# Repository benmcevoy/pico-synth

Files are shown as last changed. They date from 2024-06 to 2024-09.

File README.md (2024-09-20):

# Raspberry Pi Pico "pico-synth"

Audio synthesizer running on a Raspberyy Pi Pico device.

Currently monophonic with TWO voices.

You WILL need to make a little circuit to drop the PWM voltage from 3.3 volts to about 1.1 volts and filter low/high noise out.  Or just risk it and plug in a speaker :)

Here is an example circuit: https://learn.adafruit.com/adding-basic-audio-ouput-to-raspberry-pi-zero/pi-zero-pwm-audio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

I use `qjackctl` on linux to connect a midi keyboard via my PC.  I have not tested it directly with a MIDI controller directly attached (no PC involved), I assume it will work :)

You can find a `synth.uf2` file in the build folder which can be copied onto the Pico (hold bootsel while powering on connecting to a PC).

This is about the third C project I have written in the last thirty years, so you know... all bugs are my own.

## Pico-SDK

For PIO USB needs to be on develop, at milestone 2.1 release should be back on master.

## TinyUSB

pico-sdk ships an older version of tinyusb, so i have pulled latest of that module in order to get the newer usb host code.

Must be >= v0.17

```
# update sdk
cd pico-sdk
git submodule update --init --recursive

# update tiny-usb
cd pico-sdk/lib/tinyusb
git pull origin master
```

Run to get the dependances for pio usb.

```
python3 tools/get_deps.py rp2040
```

midi host code from:  https://github.com/rppicomidi/usb_midi_host

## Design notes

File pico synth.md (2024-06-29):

# pico-synth

DONE - solder on some headers

DONE - add a reset button pin 30 short to ground

## DONE - toolchain

installed mostly as per 

`https://raw.githubusercontent.com/raspberrypi/pico-setup/master/pico_setup.sh`

skipped OpenOCD and some pi related things

blink - it sure did

hello_world

`sudo dmesg`

shows the usb device

then we can monitor it

`sudo plink -serial /dev/ttyACM0 -sercfg 115200`

## CMAKE Build

if you just run cmake it makes an awful mess

i don't really know what i'm doing...

grabbed the example base cmake.txt and sdk import files as the basis

set the project to synth

in the synth project just include main.c to build, plus a bit of pico config

e.g.
```sh
pico_enable_stdio_usb(synth 1)
pico_enable_stdio_uart(synth 0)
```

prepare the build folder, from /src

```
mkdir build
cd build
cmake ..
```

this dumps a load of stuff in build

then cd into e.g. build/synth and

`make -j4`

or just `make`

cmake makes make.  duh...

## logging via uart

currently logging via usb.  i read that this is intensive compared to UART.

just turn on UART and turn off USB for stdio

```
pico_enable_stdio_usb(${projectName} 0)
pico_enable_stdio_uart(${projectName} 1)
```

for now, don't care.  it's more convient to use usb.

```sh
sudo plink -serial /dev/ttyACM0 -sercfg 115200
```

## wavetable on an irq

i have a header file from circle that has a sample in  it... let's nick it.

i assume that once started i have to go into some loop to stay alive...  what is the basic pattern here?

"The return code of main() is ignored by the SDK runtime, and the default behaviour is to hang the processor on exit."

so we can just loop through the sound.h array then exit.  no wukkas.

```
// set up pwm
// setup an irq to provide a nice clock
// the sample is 44.1kHz and 8 bit
```

pointer into an array is going to be *char++ something like that... to step 8 bits/byte per step

some code from the pico example:

```c
// Tell GPIO 0 and 1 they are allocated to the PWM
    gpio_set_function(0, GPIO_FUNC_PWM);
    gpio_set_function(1, GPIO_FUNC_PWM);

    // Find out which PWM slice is connected to GPIO 0 (it's slice 0)
    uint slice_num = pwm_gpio_to_slice_num(0);

    // Set period of 4 cycles (0 to 3 inclusive)
    pwm_set_wrap(slice_num, 3);
    // Set channel A output high for one cycle before dropping
    pwm_set_chan_level(slice_num, PWM_CHAN_A, 1);
    // Set initial B output high for three cycles before dropping
    pwm_set_chan_level(slice_num, PWM_CHAN_B, 3);
    // Set the PWM running
    pwm_set_enabled(slice_num, true);
```

**what is a slice?**

in the sdk docs and the datasheet it is not defined.  but i think that PWM has a master clock then subdivides that up into 8 or 16 "slices"? so each slice has some clock to tell it when to go high, go low.

https://www.codrey.com/raspberry-pi/raspberry-pi-pico-pwm-primer/

so, pin0 has associated slice number 0A  that's not HEX mind, that's 0 channel A

and pin1 is channel b e.g. 0B

so we do get 16 "channels" on 8 "slices"

**what is a wrap?**

guessing this is when the pwm counter wraps?

it's also not defined, thanks for that.

looks like

```
channelA: -___-___-___
channelb: ---_---_---_
```

so this example is not really what we want.

https://www.raspberrypi.com/documentation/pico-sdk/hardware.html#hardware_pwm

this is better but still assumes an awful lot...

https://www.raspberrypi.com/documentation/pico-sdk/hardware.html#detailed-description109

ok rtfm...

another example ticks some boxes...

```c
    // Tell the LED pin that the PWM is in charge of its value.
    gpio_set_function(PICO_DEFAULT_LED_PIN, GPIO_FUNC_PWM);
    // Figure out which slice we just connected to the LED pin
    uint slice_num = pwm_gpio_to_slice_num(PICO_DEFAULT_LED_PIN);

    // Mask our slice's IRQ output into the PWM block's single interrupt line,
    // and register our interrupt handler
    pwm_clear_irq(slice_num);
    pwm_set_irq_enabled(slice_num, true);
    irq_set_exclusive_handler(PWM_IRQ_WRAP, on_pwm_wrap);
    irq_set_enabled(PWM_IRQ_WRAP, true);

    // Get some sensible defaults for the slice configuration. By default, the
    // counter is allowed to wrap over its maximum range (0 to 2**16-1)
    pwm_config config = pwm_get_default_config();
    // Set divider, reduces counter clock to sysclock/this value
    pwm_config_set_clkdiv(&config, 4.f);
    // Load the configuration into our PWM slice, and set it running.
    pwm_init(slice_num, &config, true);

    // Everything after this point happens in the PWM interrupt handler, so we
    // can twiddle our thumbs
    while (1)
        tight_loop_contents();
```

What is sysclock frequency?  125 MHz?  this ain't no c64...

to get 44.1kHz i need a divider of?  2834.467120181

looking at some other example the wrap also affects this.

it's not clear yet.

but at 125Mhz

we can set a wrap of 254

and a divider of 12

and get 41010.498687664 Hz

close enough.

this example tweaks the sys clock to to get a nicer audio clock

https://github.com/rgrosset/pico-pwm-audio/blob/main/pico-pwm-audio.c

oh this line: `irq_set_exclusive_handler(PWM_IRQ_WRAP, on_pwm_wrap);`

well...

https://www.raspberrypi.com/documentation/pico-sdk/hardware.html#interrupt-numbers

feck.

so, i assumed the pwm level would be 16 bit.

oh, is it tied to the wrap level?

anyway, send an 8bit value works.

my clock speed was correct too.

ah, better the rp2040 datasheet has more info

https://datasheets.raspberrypi.com/rp2040/rp2040-datasheet.pdf

- interrupt request and DMA request on counter wrap

well that's handy....

wrap is a terrible name, it's the trigger level.

if i want to send 16bit samples i set wrap to 65535

oh, which gives me 1900 HERTZ!  bit slow...

yes that seems to be the case.  but the clock speed is no good

i can run at 12 bit and get about 31kHz

sounds correct too.

ok.

so for the reality situation

8 bit sound

a wrap of 255 or so

and in fact our original values are pretty good for 44.1kHz

we can probably drop to 22kHz

wrap:255

div:22

lands us at about 22.3kHz

as our sample is 44.1 we have to increment the index TWICE to make it about right.,

that is my hypothesis, let us try.

it is so.

ok, better read the rp2040 datasheet then...

Before looking at DMA I want to look at buffers.

I am thinking I need two buffers.  one is being streamed to the PWM while the other is filled.

when the buffer is empty i swap over.

is that normal? double buffering?

a search says "yes" this is sane.  the decision is mainly one of latency.

for DMA double bufferering appears to be necessary.

In BELA they use block based processing, which is buffers.

```cpp
// setup() runs once at the beginning of your program
bool setup(BelaContext *context, void *userData)
{
    // etc
}

// render() is called repeatedly by Bela for each audio block
void render(BelaContext *context, void *userData)
{
    // etc
}

// cleanup() runs once at the end of the program
void cleanup(BelaContext *context, void *userData)
{
}
```

the context provides several things, audio buffers, analog buffers, digital buffers, bidirectional too.

we care only for an audioOut buffer and samplesElapsed

also, I do not need to care about "frames" that is how many channels per sample do i need to fill.

it's one channel, mono so it's all 1.  hence just  samplesElapsed (u64)

userData is just some user struct that get passed around, so more user context data. i do not care for now.

how did I write my synth?  I made a `MonoWaveStream` that just fills a buffer when asked. and it get's it's next byte from `_voice.Output(Time).Out.Value`

`Time` then is `samplesElapsed`

so, trying to port my code...

I want a `Device` that has two buffers and 

- a pointer that tracks the current buffer 
- a read index

on the IRQ we just read another value from the buffer.

the device should also handle setting up sample rate but not bit depth as we can't really go beyond 8 bit

my code return `short` 16 bit samples. ok, deal with that later.

the Pico SDK is C/C++ so I can use that if need be.

how do i fill the buffer while continuing to service the irq?

threads? trigger another IRQ when swapping buffers?

skimming throught he examples, DMA offers control block chain - which is basically an array of buffers, or raise an IRQ when data is needed

there are timers, which use the system timers e.g. alarms

i feel like raising another IRQ when we need data is fine and sane.

there is a `pico_audio_pwm` sample in the `pico-extras`.  not making too much sense of it but:

it does some fancy things, like over-sampling and noise dithering (huh!?)

but how does it get it's data?

it defines audio buffer producer and consumer pools.

i can't follow the code but it looks like a DMA irq fires and asks for a new buffer....

i imagine the nice thing about using DMA+PIO is that a lot of the work that is NOT directly related to generating the next sample is offloaded to hardware and is very cycle exact etc.

but today that is beyond me.

SO.

## buffers and dma

Double buffer and use an IRQ to request more data.
do not care about DMA at this time.

fill the buffer so we can continuosly play a sine wave or something

ok. 

`Amplitude = sin(2*pi*f*t)`

and 

`t = samplesElapsed/sampleRate`

and sample rate as given in the rp2040 datasheet

`fsys = 125 MHz`

`fpwm = fsys/period`

`period = (WRAP+1)*(phase_correct+1)*(DIV+15/16)`

so we use wrap =254 and div =22 to get fpwm=21370.946198643

and that makes a noise that sounds fairly crap, lots of clicks and drift. 

lets add phase correction (halve the divider)

```
    pwm_config_set_clkdiv(&config, 11.f);
    pwm_config_set_wrap(&config, 254);
    pwm_config_set_phase_correct(&config, true);

```

not much better

hmm, wonder if it rentrant? make the buffers bigger

oh. that is an issue,  still clicks but much less.

BIGGER! 8k buffer!

actually it's a phase problem.  regular click.  

actually it's a bunch of bugs.  using `_samplesElapsed` which is still being incremented by the core0 while core1 tries to use it.

marshalling data to core1?  i think the FIFO is used? i just copy the value.  solid.

ok, reduce the buffer! 1k, just fine.

yeah buffer can be tiny, 32 bytes lol.

1 byte even.  ok, there's no real latency so far.

sweet as.

### PWM IRQ

From the docs:

"The same [PWM] pulse which sets the interrupt flag in INTR is also available as a one-cycle data request to the RP2040 system DMA. For each cycle the DMA sees a DREQ asserted, it will make one data transfer to its programmed location, in as timely a manner as possible. In combination with the double-buffered behaviour of CC and TOP, this allows the DMA to efficiently stream data to a PWM slice at a rate of one transfer per counter period. Alternatively, a PWM slice could serve as a pacing timer for DMA transfers to some other memory-mapped hardware."

DMA IRQ or DREQ seems like the go then.  next step.

Also: "the PWM block can also be used as a source of regular interrupt requests for non-PWM-related purposes"

Like polling MIDI or ADC...

Choice.

### DMA/DREQ

I'm struggling to see what benefit I would get here...

It seems the DMA will stream data to the PWM on each WRAP IRQ, which is good

Then a DMA IRQ will fire when it's buffer is empty?

we can then more or less immediately swap buffers and let DMA continue while then going on to fill the next buffer

which looks like it could all happen on core0

in this way the PWM IRQ work becomes completely offloaded to hardware

and the actual work of producing samples only needs to be checked for at the right time, when the buffer is empty

ok.  so maybe i can see the benefit.

This example is helpful, as it is basically what I want to do, ping-pong between two buffers.

https://github.com/raspberrypi/pico-examples/issues/112#issuecomment-1405075256

also

https://github.com/GregAC/pico-stuff/blob/main/pwm_dma/pwm_dma_interrupt_sequence.c

OK, let's give that a crack.

managed to bodge that together.  It is working but sounds quite bad - buzzy.

might look on the old oscilloscope.  A PICO SCOPE no less!

the old way, just the irq on the pwm produces some PWMish looking stuff
the new way produces a spike at 440Hz, click click click

i assume my config is not good.

i'll go read the pico-extras example of pwm audio.

well, I came across some info - samples MUST be 16 bit.  I do not understand the data sheet, but this works.

## core0 synth

when the time comes:

I am not confident to be able to port my C# code, it's all higher order functions and what not, and not straight forward at all to convert to C AFAIK.

But the maths is the same. so good enough as a reference.

- define a voice struct
DONE - waveforms
DONE - phase accumulation 
- trigger play new note
- envelope control
- filter
- 

oh my.

SO a sinewave, that was fine and dandy.
Noise, no problem.

Triangle?

blimey.

```c
double triangle(AudioContext_t *context, double frequency, double amplitude)
{
    // TODO: well this don't sound right...
    _phase += TWOPI * frequency / context->SampleRate;

    if (_phase >= TWOPI)
        _phase -= TWOPI;

    return (asin(sin(_phase)) / M_PI_2) * amplitude;
}
```

which is more or less the same as c#

```c#
        /// <summary>
        /// A triangle wave form.
        /// </summary>
        public static W Triangle() => (t, f, w, p) => Amplitude.Scale(Asin(Sin(Angle(f, t))) / HalfPI);

        public static double Angle(double t, double f) => TwoPI * f * t;

```

Time here is essentially SamplesElapsed/SampleRate.

In C# there is implicit conversion to double.  In C there is not.

The C code avoids this time calculation but has some odd phase discontinuity which I can't work out...

With a small buffer it sounded very odd, very distorted.
At a larger buffer size I hear the click as it jumps in phase.

I can printf out the contents of the buffers
and it is a nice looking triangle wave.

much confused

Square - OK. I have ignored pulsewidth for now.
Saw - OK.  

ok that's waveform now.

### trigger play note

hmmm.  

simply :

some player, that sets a frequency, sleeps for some time, sets a new frequency, etc loop

at this point we need some kind of context to represent state

let's add a Voice struct to the audio context.

Voice:
 frequency
 waveform

good enough for now.

```c
typedef struct Voice
{
    double frequency;
    enum waveform waveform;

} Voice_t;
```

```c
    while (true)
    {
        _context->Voice.frequency = 440;
        sleep_ms(200);
        _context->Voice.frequency = 660;
        sleep_ms(200);
        _context->Voice.frequency = 880;
        sleep_ms(200);
        _context->Voice.frequency = 660;
        sleep_ms(200);
    }
```

does it for me.

next up:

DONE - a frequency/note table
NAH DO IT LATER - multiple voices which will create an audioframe
NAH DO IT LATER - mix the voices

now i can test things a bit better
it sounds fairly crap lol :)

the waveforms have phase accumulation errors.  
and using sleep_ms instead of something tied to the sample rate makes... not much sense

OK.  So what seems to be happening is,

the waveform LOOKS good when i log it out and graph it.  it's perfect.

the code CRASHES when the buffer swaps ONLY on triangle. and the dma IRQ keeps on playing the same buffer over and over

hence the clicking...

why you crash?

to debug I need a SWD debugger - the best option is another pico, which I do not have to hand unless I rip apart something else, which I don't wanna do...

but knowing that it is actually crashing and not some phase problem as i thought may be enough to triage that bad boy

ok.  after some stuffing around it seems that arcsine is too slow and the buffers get corrupted.  the assertion is that arcsine is slower than 1/SampleRate seconds

so let's set the sample rate to 16384 or 8000 or something and see...

yep.  works* but sounds like crap.  ok. 

i wasn't expecting this kind of time budget.

hello stackoverflow:

https://stackoverflow.com/questions/3380628/fast-arc-cos-algorithm

```c
double acos(x) {
   return (-0.69813170079773212 * x * x - 0.87266462599716477) * x + M_PI_2;
}
```

this is fast enough and sounds OK.
scanning through the ARM M0+ datasheets looks like trig is not on the chip.
could consider a Lookup table instead i suppose.

ARM provides CMSIS-DSP optimised libraries.  
seems I have arm_math.h, does it have arccos or arcsin?

appears not.  but i do see a bunch of FIR filter functions.  looks interesting.

seems with the approximate arccos i can ran at 35kHz, so I have a little headroom if i am targeting 22kHz.
and I can always overclock.

DO i need to look at the emitted assembly?  Oh my C...

No issues in the C# version, but then again it was running on a processer that is 30+ times faster with trig intrinsics...

### Wavetable

as per the Bela example with linear iterpolation:

```c

double triangle_wt(AudioContext_t *context)
{
    uint indexBelow = floor(_readPointer);
    uint indexAbove = indexBelow + 1;

    if (indexAbove >= WAVE_TABLE_LENGTH)
        indexAbove -= WAVE_TABLE_LENGTH;

    double fractionAbove = _readPointer - indexBelow;
    double fractionBelow = 1.f - fractionAbove;

    double value = context->Voice.amplitude * 
        (fractionBelow * _triangleWaveTable[indexBelow] + fractionAbove * _triangleWaveTable[indexAbove]);

    _readPointer += WAVE_TABLE_LENGTH * context->Voice.frequency / context->SampleRate;

    while (_readPointer >= WAVE_TABLE_LENGTH)
        _readPointer -= WAVE_TABLE_LENGTH;

    return value;
}

```

can now run at ~55khz

table for triangle generated:
```c
    for(unsigned int n = 0; n <WAVE_TABLE_LENGTH/2; n++)
    {
        _triangleWaveTable[n] = -1.0 + 4.0 *(float)n/(float)WAVE_TABLE_LENGTH;
    }
    
    for(unsigned int n = WAVE_TABLE_LENGTH/2.f; n <WAVE_TABLE_LENGTH; n++)
    {
        _triangleWaveTable[n] = 1.0 - 4.0 *(float)(n- WAVE_TABLE_LENGTH/2.f)/(float)WAVE_TABLE_LENGTH;
    }

```
wow.  i use float instead of double and now can run at ~82kHz

### Envelope

DONE - remove amplitude from voice_t and let envelope control it

DONE - NoteOn - trigger attack-decay-sustain (onset)

DONE - NoteOff - trigger release

well.  I went down a road of trying to use function pointers, but it's hard.  no idea how to get closures.

i had something like:

```c

// function pointer as a member of voice_t
float (*envelopeGenerator)(float, float, float);

// function i was trying to use
// the idea was as each section of the ADSR elapsed I would point to the next function to generate the next section...

// roughly translated from c# version
float attack(float timeInitial, float time, float duration){
    if(!has_elapsed(timeInitial, time, duration))   
        ? linear_easing(timeInitial, time, duration, 0.f, 1.f)
        : 1.f; 
}

envelopeGenerator = &attack;

// etc
```

but yeah, nah.  too hard for me.

Too many float's there too.  So, after watching another Bela video and thinking about the SID chip.

SID has a control register a single bit to indicate voiceOn or voiceOff

Bit #0: 0 = Voice off, Release cycle; 1 = Voice on, Attack-Decay-Sustain cycle.

so I added a flag to the voice `bool trigger_attack`

and made a state machine as suggested by Bela.  

and all good.  the actual state that is held in `envelope.c` will need to migrate to the voice I assume at some stage.

## UART and SWD with picoprobe

well good, I got a couple more pico in the mail so I have made one up as UART/SWD.  This frees up the USB port for midi I hope and helps debugging and deploying.

UART works.  updated the cmake file to switch from USB and all good.

build and install openocd as per datasheet instructions

SWD deploys the elf file not the uf2

`openocd -f interface/raspberrypi-swd.cfg -f target/rp2040.cfg -c "program synth.elf verify reset exit"`

datasheet instructions ar enot quite correct but the original gist at the top of this document is good.

I now get 

```
Open On-Chip Debugger 0.11.0-g8e3c38f (2023-07-23-19:55)
Licensed under GNU GPL v2
For bug reports, read
        http://openocd.org/doc/doxygen/bugs.html
Error: The specified debug interface was not found (bcm2835gpio)
The following debug adapters are available:
1: ftdi
2: usb_blaster
3: ft232r
4: presto
5: usbprog
6: openjtag
7: jlink
8: vsllink
9: rlink
10: ulink
11: arm-jtag-ew
12: hla
13: osbdm
14: opendous
15: sysfsgpio
16: aice
17: picoprobe
18: cmsis-dap
19: xds110
20: st-link
```

picoprobe is available, so the openocd command 'aint right.

```sh
sudo openocd -f interface/picoprobe.cfg -f target/rp2040.cfg -c "program synth.elf verify reset exit"

Open On-Chip Debugger 0.11.0-g8e3c38f (2023-07-23-19:55)
Licensed under GNU GPL v2
For bug reports, read
        http://openocd.org/doc/doxygen/bugs.html
Info : only one transport option; autoselect 'swd'
adapter speed: 5000 kHz

Info : Hardware thread awareness created
Info : Hardware thread awareness created
Info : RP2040 Flash Bank Command
Error: Failed to open or find the device
Error: Can't find a picoprobe device! Please check device connections and permissions.
Error: No Valid JTAG Interface Configured.
```

The internet says try this:

`openocd -f interface/cmsis-dap.cfg -c "adapter speed 5000" -f target/rp2040.cfg -s tcl`

Works with sudo.

That command opens gdb for debugging.

let's try (second attempt actually...)

```sh

sudo openocd -f interface/cmsis-dap.cfg -f target/rp2040.cfg -c "adapter speed 5000" -c " program synth.elf verify reset exit"

```
and gold.

gonna add some sh scripts to monitor uart and deploy (and make) the elf.

## core1 midi (or adc knob twiddling)

### first steps

first lets get the example project working

maybe i can try to just echo midi commands back on UART?

lets build the midi_test example

https://github.com/hathach/tinyusb/blob/master/docs/reference/getting_started.rst

groovy

shows up as a midi device, used qjackctl to connect and I hear the example pattern.

the example also implements receiving midi and disacrds it

so loopback over UART:

```sh
$ sudo plink -serial /dev/ttyACM0 -sercfg 115200

midi received 9 144 57 100
midi received 9 144 60 96
midi received 8 128 60 0
midi received 9 144 62 68
midi received 8 128 62 0
midi received 9 144 65 72

```
woot.

8 - note off
128 - velocity - kinda nonsense can ignore
60 - note number C3
x - ignored

9 - note on
144 - velocity 
60 - note number
x - ignore

this data looks wrong

0x9n  where n is the channel.

not getting that?

ok.

9 144 57 100

- 9 this is noteon (9), 
- 144 is %1001 0000  which is 0x90  or note on channel 0
- 57 note number
- 100 velocity

command, command_channel, note, velocity

alrighty.  makes sense now.  can't find any documentation.  

note really standard.  i guess the first byte is trying to be helpful.

ok.  i think I can now try to integrate this into my code.

and again, just getting it to echo for now.

Excellent.  

DONE - there is _TUSB_MIDI_DEVICE_H_  tinyusb midi device

DONE - add midi note number table, note needed used the note to pitch funciton instead.

DONE - add midi command noteon, noteoff

DONE - midi events should be in a FIFO queue that is supplied with the current write buffer so we can catch up on what and when but tinyusb should be doing this i assume.

well darn.

for some reason it is not actually playing on NOTEON

oh ho ho

had not set any envelope values. lol.

working good!

## polyphony

hmm, want to think about for this a while.

a monophonic synth can have several voices or OSCILLATORS but they combine to make the actual voice sound

i think in the first place some monophonic behaviour is the plan

### Note priority

https://en.wikipedia.org/wiki/Polyphony_and_monophony_in_instruments#Note_priority_of_synthesizer

I have allowed three voices now, but I am hitting performance constraints again, had to halve the sample rate for now.

Currently running at ~18.8kHz

I would like to convert the floats to fixed point, as the pico (Cortex M0+) has no FPU...

uh-huh.  not sure how to use `<stdfix.h>`  - keeps saying _Accum is undefined.

I have implemented a very dodgy note priority.  a dodgy stack.

i'll have to try again.  it'll do for now.

add detune as a multiplier.  so e.g. `frequency * 1.01` to tune a little higher

## Filters

ARM provides CMSIS SCIENCE library!  DSP and what not.

What kinda filter did I have in C#?

```c#
        // Calculate the filter coefficients based on the given parameters
        // Borrows code from the Bela Biquad library, itself based on code by
        // Nigel Redmon
```
Seems I nicked it.

Appears to be a "second-order IIR filter".  CMSIS offers at least three variations of an IIR filter.

I'll start by porting my code and being happy if it works.

for now filter is at the audio context level, so applies to the final output and not per voice.

ok.  that seems to work :)

I am going to swap the order of things now and implement the CC commands so I can start knob twiddling.

performance is tanking :) down to ~13kHz now.

## MIDI CC

looks like the tinyusb library does not support usb midi host, so I don't think I can plug a midi controller in directly (yet). 
I found a project that has patched in support for this.

Or alternatively look at using a DIN plug and midi over UART.  Sounds like work.

- MIDI CC 70-79
- MIDI CC70	Sound Controller 1	A control for affecting how the sound is produced. Used for filters, effects etc.
DONE - MIDI CC 71	Sound Controller 2	Allocated to filter resonance/Q.
- MIDI CC 72	Sound Controller 3	Allocated to the amp envelope release time. Changes how long notes fade out.
- MIDI CC 73	Sound Controller 4	Allocated to the amp envelope attack time. Changes how fast the volume rises from the keypress to max volume.
DONE - MIDI CC 74	Sound Controller 5	Allocated to the filter cutoff frequency Hz value.
- MIDI CC 75 – 79	Sound Controller 6-10	An extra control for affecting how the sound is produced. Used for filters, effects etc. 
- MIDI CC 94	Effect 4 Depth	Usually a control for the amount of detuning.

## Performance

profiling - measure first. might be some low hanging fruit here.

i did some quick measuring and the FILTER is a pig :)

the envelope generation is almost all linear interpolation.  Pico has a hardware interpolator.  Just no idea how to use it...

fixed point math.

I read somewhere the interpolator can also be used for reading the wave table. Maybe.

### simple tweaks

baseline clk_div 30

comment out envelope
clk_div 29

comment out filter
clk_div 18

remove tanf call
clk_div 24

1 voice and no filter
clk_div 9

avoid division in wave table lookup
clk_div 22 !!! wow

compute filter co-eff on midi cc instead of constantly
clk_div 12

By precomputing the "wave table stride" I can avoid a division in the tight loop that populates the buffer
this bumps us from ~16kHz to ~22kHz

By only calculating the filter coefficients when the filter settings change, i.e. when a midi cc command occurs
this bumps us from ~22kHz to ~40kHz

so back in business.

I need to spike out a seperate test project to investigate fixed point/stdfix.h

OK - my tests above were no good.  was not actually using the wavetable.

## Noise

I want tonal noise.  I am not sure what it is called, but it's noise that is correlated to a frequency.

Reviewing the c64 and the NES - both use a LSFR.  Setting the frequency changes the timing of the LFSR, e.g. high frequency means the LFSR runs at a higher clock.

I have implemented two LFSR for pseudo random numbers.  One is the actual c64 algorithm (as near as people can make out).

I **think** I need an IRQ or some timer that will generate the next random/PRNG into a register.  Then I can just read that register.

The IRQ would ideally want to be per voice and timing of the IRQ directly proportional to the voice frequency.  I think.

This would mimic (I think!) what happens on the NES/C64.

This is apparantly just called periodic random noise or just pseudo random noise.

I've put this on the back burner for now.  This is what I had but simplified for the time being to just the prng method.

```c
#ifndef SYNTH_NOISE_
#define SYNTH_NOISE_

#include <stdlib.h>

#include "pico/stdlib.h"

static uint16_t _seed = 17;
static int a = 1;
static int b = 5;
static int c = 2;

// https://en.wikipedia.org/wiki/Xorshift
float synth_noise_next_prng() {
    _seed ^= (_seed << a);
    _seed ^= (_seed >> b);
    _seed ^= (_seed << c);
    // 16 bit PRNG scaled to -1..1
    return _seed / 32768.f - 1.f;
}

float synth_noise_next_random() {
    return (rand() / (float)(RAND_MAX)) * 2.f - 1.f;
}

/* Test a bit. Returns 1 if bit is set. */
static bool bit(long val, uint8_t bitnr) {
    return (val & (1 << bitnr)) ? 1 : 0;
}

// http://www.sidmusic.org/sid/sidtech5.html
static uint32_t reg = 0x7ffff8; /* Initial value of internal register*/
static uint8_t output;
static bool bit22; /* Temp. to keep bit 22 */
static bool bit17; /* Temp. to keep bit 17 */

/* Generate output from noise-waveform */
float synth_noise_next_c64() {
    /* Pick out bits to make output value */
    output = (bit(reg, 22) << 7) | (bit(reg, 20) << 6) | (bit(reg, 16) << 5) |
             (bit(reg, 13) << 4) | (bit(reg, 11) << 3) | (bit(reg, 7) << 2) |
             (bit(reg, 4) << 1) | (bit(reg, 2) << 0);

    /* Save bits used to feed bit 0 */
    bit22 = bit(reg, 22);
    bit17 = bit(reg, 17);

    /* Shift 1 bit left */
    reg = reg << 1;

    /* Feed bit 0 */
    reg = reg | (bit22 ^ bit17);

    // scale 8 bit number to -1..1
    return output / 128.f - 1.f;
}

#endif
```

## Settling on an instrument design

Now we have a clearer picture about the constraints we are operating in.

I have also implemented **enough** features to start to get a feel.

Need to settle on an instrument design that works in these constraints.

For instance - a monophonic synth might yield a simple design, as envelope could be on the final mix instead of per voice.

Or the filter could be invested in, as it sounds a bit weak at the moment.

Maybe I could string a few pico together with I2S as a kinda modular physical/digital synth?  That is an idea.  One pico does oscillator, another filter, another echo, etc.

features:
- osc3 as LFO 
- filter envelope

DONE - monophonic, two oscillators

DONE - amplitude envelope (on the mix)

and if we have the cpu
- arp
 
DONE - delay

and we need patches or some kinda controller with lots of knobs

so my work is cut out.

## monophonic

DONE - fix the note priority

I looked to BELA once more, they demonstrate a most recent note priority schem, so I implemented it. 

DONE - only voice1+2

## Amplitude envelope

DONE - only voice1+2 - applies to mix

## Filter envelope

- MIDI CC 72	Sound Controller 3	Allocated to the amp envelope release time. Changes how long notes fade out.
- MIDI CC 73	Sound Controller 4	Allocated to the amp envelope attack time. Changes how fast the volume rises from the keypress to max volume.

## LFO

has to feed into e.g:

- detune v2
- filter resonance
- filter cutoff
- Amplitude envelope sustain

## Arppegiator

um? up down random

how to program?  hold down many keys?  use a chord table?

## Echo echo echo

add a circular buffer.  i like it.

## Fixed point

After watching a few youtube videos I have manged to start moving this to a fixed 16.16 value.

Slowly getting rid of floats...

There is AFAIK a hardware integer divider so we should be OK.

## Populating wavetable

as I keep forgetting...

```c
    static fix14 waveTable[WAVE_TABLE_LENGTH] = {0};

    // sine
    for(int i = 0; i < WAVE_TABLE_LENGTH; i ++){
        waveTable[i] = float2fix14(sin(TWO_PI * (float)i / (float)WAVE_TABLE_LENGTH));
        printf("%d, ",  (waveTable[i]) );
    }

    // triangle
    for(int i = 0; i < WAVE_TABLE_LENGTH/2; i ++){
        waveTable[i] = float2fix14(-1.0 + 4.0 * (float)(i)/(float)WAVE_TABLE_LENGTH);
        printf("%d, ",  (waveTable[i]) );
    }
     
    for(int i = WAVE_TABLE_LENGTH/2; i < WAVE_TABLE_LENGTH; i ++){
        waveTable[i] = float2fix14(1.0 - 4.0 * (float)(i - WAVE_TABLE_LENGTH/2)/(float)WAVE_TABLE_LENGTH);
        printf("%d, ",  (waveTable[i]) );
    }

    // saw
    for(int i = 0; i < WAVE_TABLE_LENGTH; i ++){
        waveTable[i] = float2fix14(
            0.5 * sin(1.0 * TWO_PI * (float)i/(float)WAVE_TABLE_LENGTH) +
            0.25 * sin(2.0 * TWO_PI * (float)i/(float)WAVE_TABLE_LENGTH) +
            0.125 * sin(3.0 * TWO_PI * (float)i/(float)WAVE_TABLE_LENGTH) +
            0.0625 * sin(4.0 * TWO_PI * (float)i/(float)WAVE_TABLE_LENGTH) 
            // and add more harmonics as you wish
         
        );
        printf("%d, ",  (waveTable[i]) );
    }
```

I found life is easier if I just one representation for every thing, envelope, waveform, etc, e.g. fix16.

## Overclocking

Use ` set_sys_clock_khz(240000, true);` 

Do this before `stdio_init_all();`  or you must call `setup_default_uart()` afterwards.

Not all clock frequencies work - there is a python script in the sdk:  `python3 vcocalc.py 240`

```
cd ./pico-sdk/src/rp2_common/hardware_clocks/scripts 
python3 vcocalc.py 240
```

```sh
Requested: 240.0 MHz
Achieved: 240.0 MHz
REFDIV: 1
FBDIV: 120 (VCO = 1440.0 MHz)
PD1: 6
PD2: 1
```

give it a clock in MHz and convert to the result to kHz.

The flash memory becomes unstable over 300MHz.  There are some cmake settings you can use to set the SPI clock divider.  I did not try too hard.

# TODO:

losing the plot

- the cortex m0+ has a hardware multipler and divider `MULS` but it is 32x32 bits with a 32 bit result. Use 16 bit fixed point and try and use straight integer more, especially for durations as they are really just "how may samples do i wait"
- implement usb host for midi (see: https://github.com/rppicomidi/midi2usbhost)
- move the I/O polling to core1idi2usbhost)
- move the I/O polling to core1
- implement arp
- revisit instrument design
- move this to a hardware design - knobs! analog multiplexer! blinky leds! I kinda want to use a LED matrix and have some ridiculous colors and patterns playing too. might need another pico driving a hub75 board or something.
- review/steal (sorry "be inspired by") from https://github.com/juandagilc/Audio-Effects/tree/master and https://github.com/PaulStoffregen/Audio

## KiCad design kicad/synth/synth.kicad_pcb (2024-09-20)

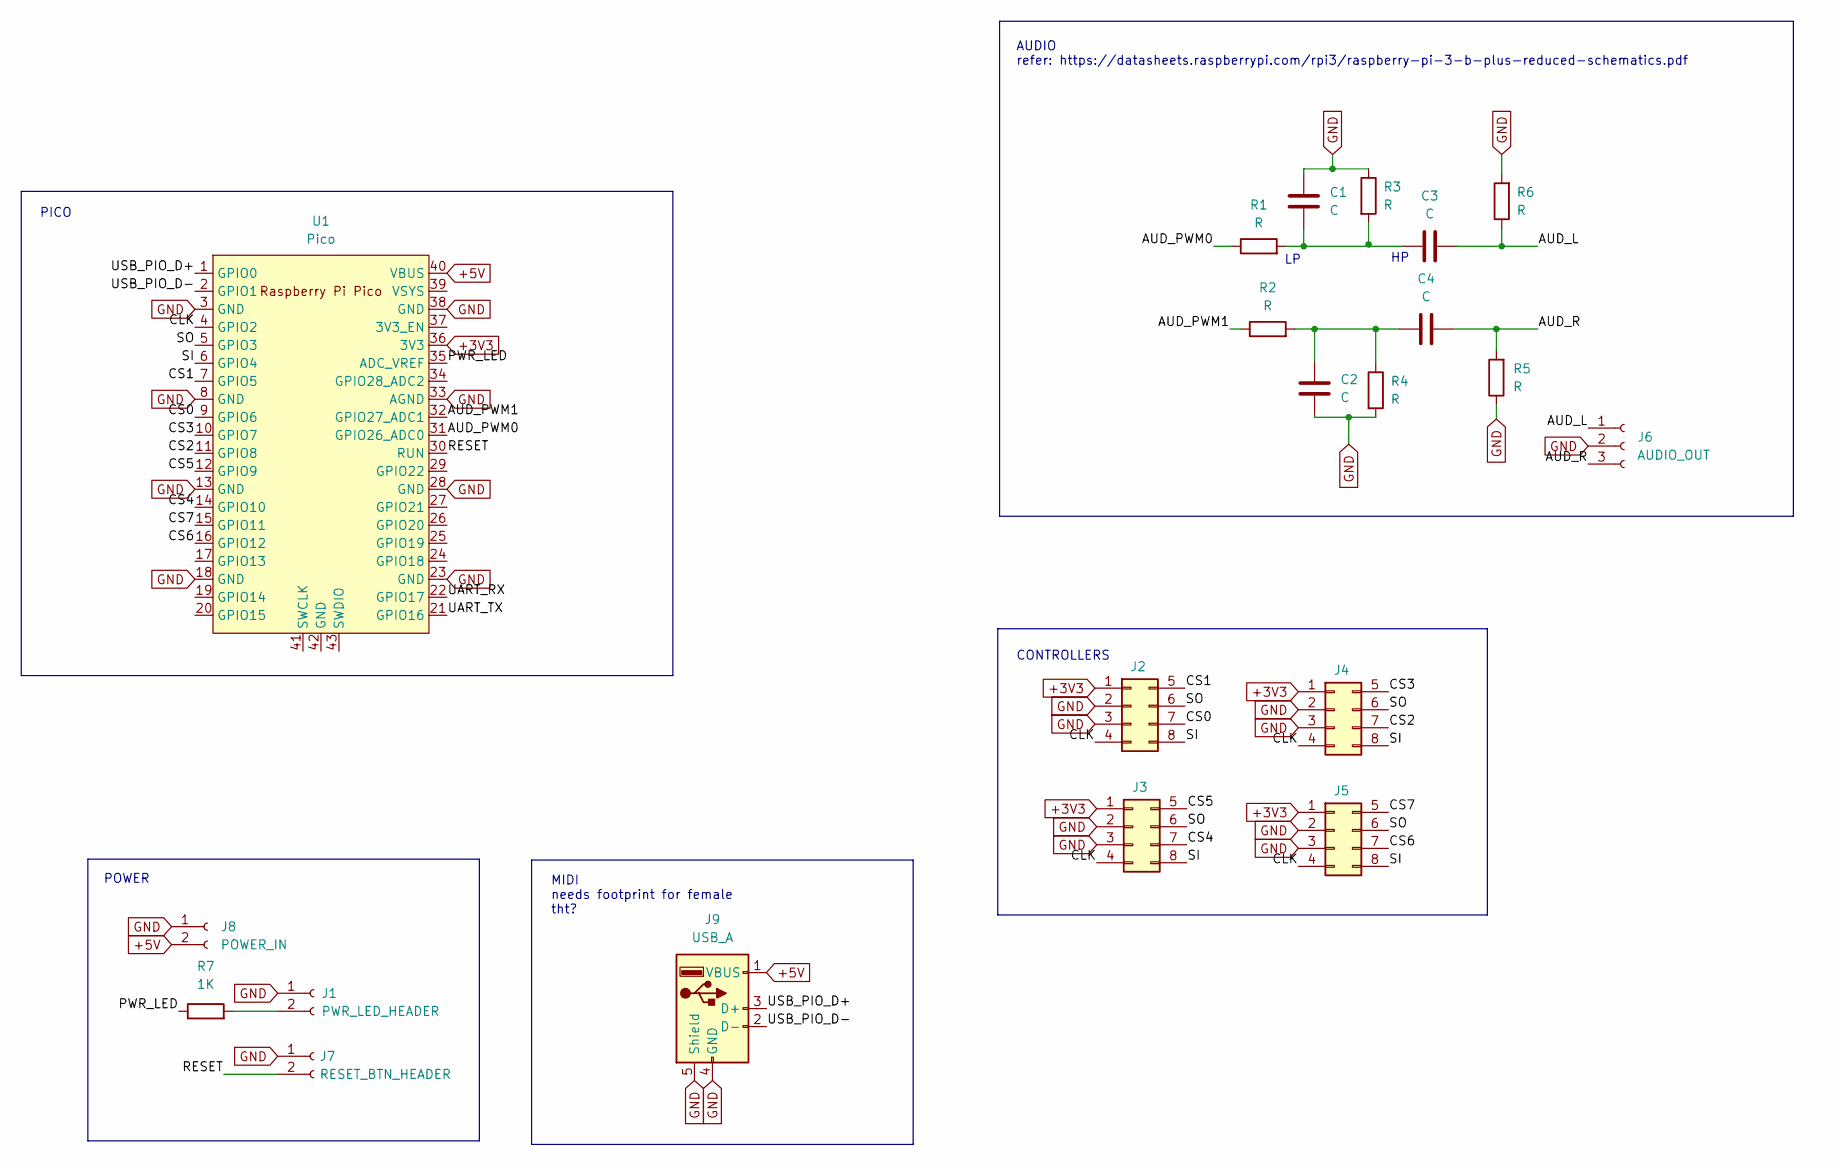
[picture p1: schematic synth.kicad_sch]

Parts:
C1, C2, C3, C4: C; C_0805_2012Metric_Pad1.18x1.45mm_HandSolder
J1: PWR_LED_HEADER; PinHeader_1x02_P2.54mm_Vertical
J2, J3, J4, J5: Conn_02x04_Top_Bottom; IDC-Header_2x04_P2.54mm_Vertical_SMD
J6: AUDIO_OUT; PinHeader_1x03_P2.54mm_Vertical
J7: RESET_BTN_HEADER; PinHeader_1x02_P2.54mm_Vertical
J8: POWER_IN; PinHeader_1x02_P2.54mm_Vertical
J9: USB_A; USB_A_CNCTech_1001-011-01101_Horizontal
R1, R2, R3, R4, R5, R6: R; R_0805_2012Metric_Pad1.20x1.40mm_HandSolder
R7: 1K; R_0805_2012Metric_Pad1.20x1.40mm_HandSolder
U1: Pico; RPi_Pico_SMD_TH

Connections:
+3V3: J2.1, J3.1, J4.1, J5.1, U1.36 (3V3)
+5V: J8.2, J9.1 (VBUS), U1.40 (VBUS)
/AUD_L: C3.2, J6.1, R6.1
/AUD_PWM0: R1.1, U1.31 (GPIO26_ADC0)
/AUD_PWM1: R2.1, U1.32 (GPIO27_ADC1)
/AUD_R: C4.2, J6.3, R5.2
/CLK: J2.4, J3.4, J4.4, J5.4, U1.4 (GPIO2)
/CS0: J2.7, U1.9 (GPIO6)
/CS1: J2.5, U1.7 (GPIO5)
/CS2: J4.7, U1.11 (GPIO8)
/CS3: J4.5, U1.10 (GPIO7)
/CS4: J3.7, U1.14 (GPIO10)
/CS5: J3.5, U1.12 (GPIO9)
/CS6: J5.7, U1.16 (GPIO12)
/CS7: J5.5, U1.15 (GPIO11)
/PWR_LED: R7.1, U1.35 (ADC_VREF)
/RESET: J7.2, U1.30 (RUN)
/SI: J2.8, J3.8, J4.8, J5.8, U1.6 (GPIO4)
/SO: J2.6, J3.6, J4.6, J5.6, U1.5 (GPIO3)
/UART_RX: U1.22 (GPIO17)
/UART_TX: U1.21 (GPIO16)
/USB_PIO_DI: J9.2 (D-), U1.2 (GPIO1)
/USB_PIO_DO: J9.3 (D+), U1.1 (GPIO0)
GND: C1.1, C2.2, J1.1, J2.2, J2.3, J3.2, J3.3, J4.2, J4.3, J5.2, J5.3, J6.2, J7.1, J8.1, J9.4 (GND), J9.5 (Shield), R3.1, R4.2, R5.1, R6.2, U1.3 (GND), U1.8 (GND), U1.13 (GND), U1.18 (GND), U1.23 (GND), U1.28 (GND), U1.33 (AGND), U1.38 (GND)
unnamed: C1.2, C3.1, R1.2, R3.2
unnamed: C2.1, C4.1, R2.2, R4.1
unnamed: J1.2, R7.2

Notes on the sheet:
POWER
CONTROLLERS
MIDI needs footprint for female tht?
PICO
AUDIO refer: https://datasheets.raspberrypi.com/rpi3/raspberry-pi-3-b-plus-reduced-schematics.pdf

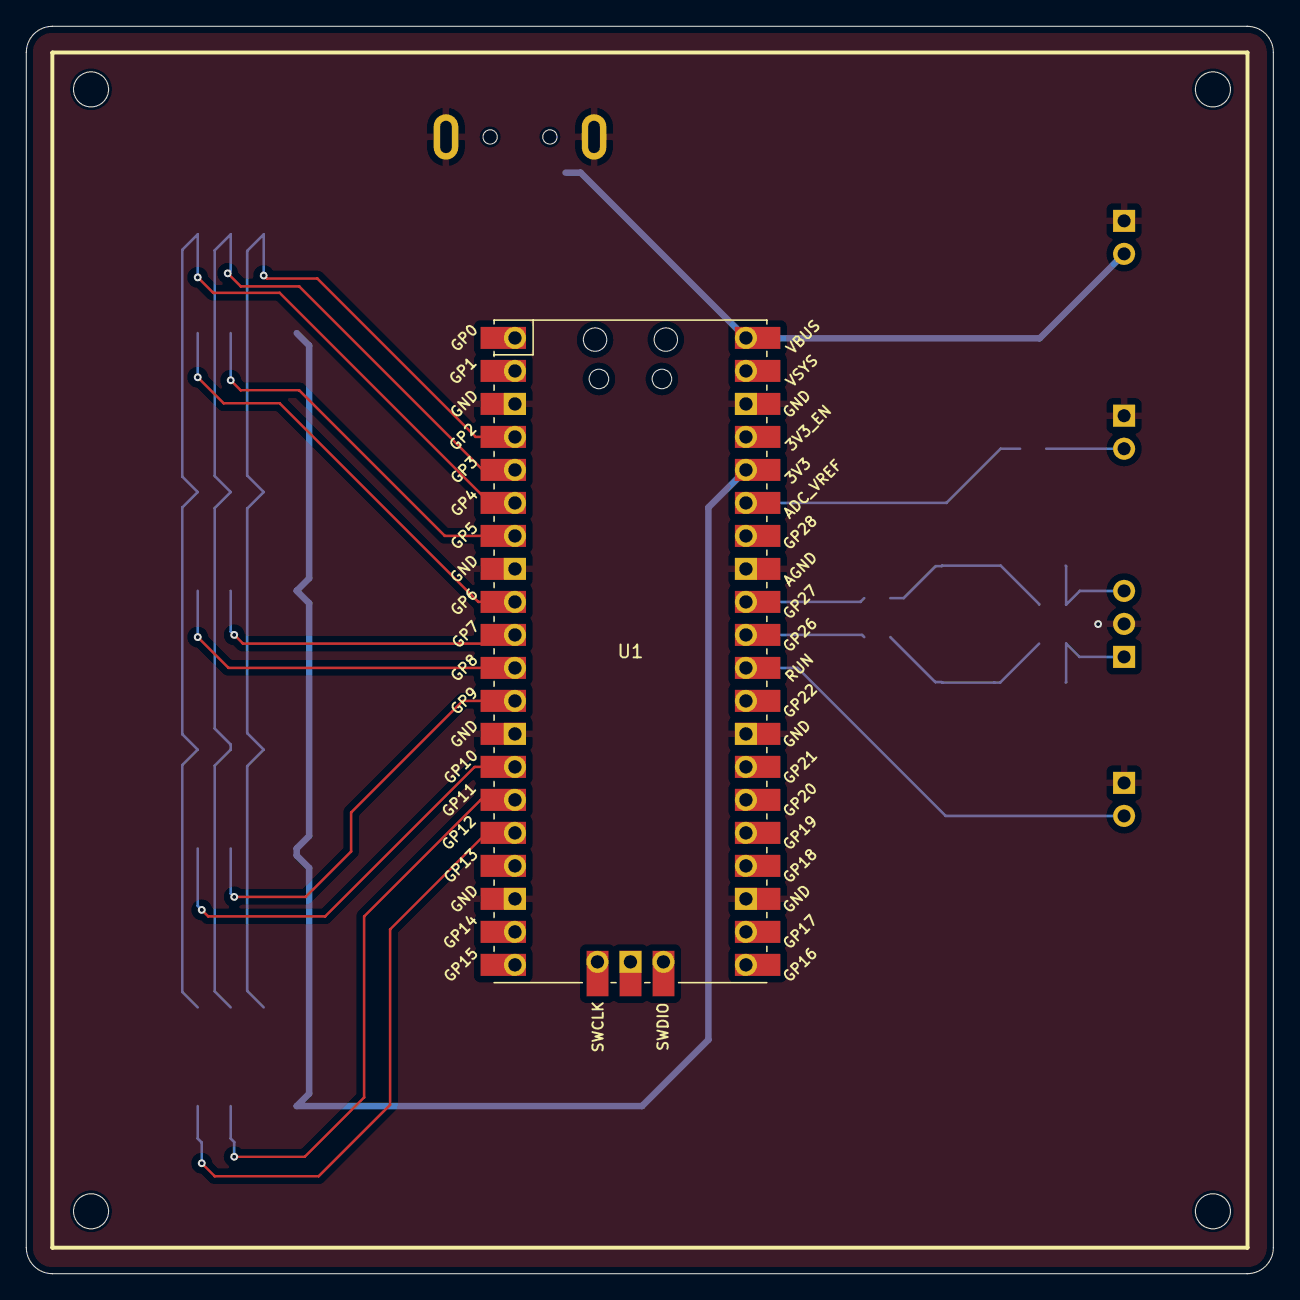
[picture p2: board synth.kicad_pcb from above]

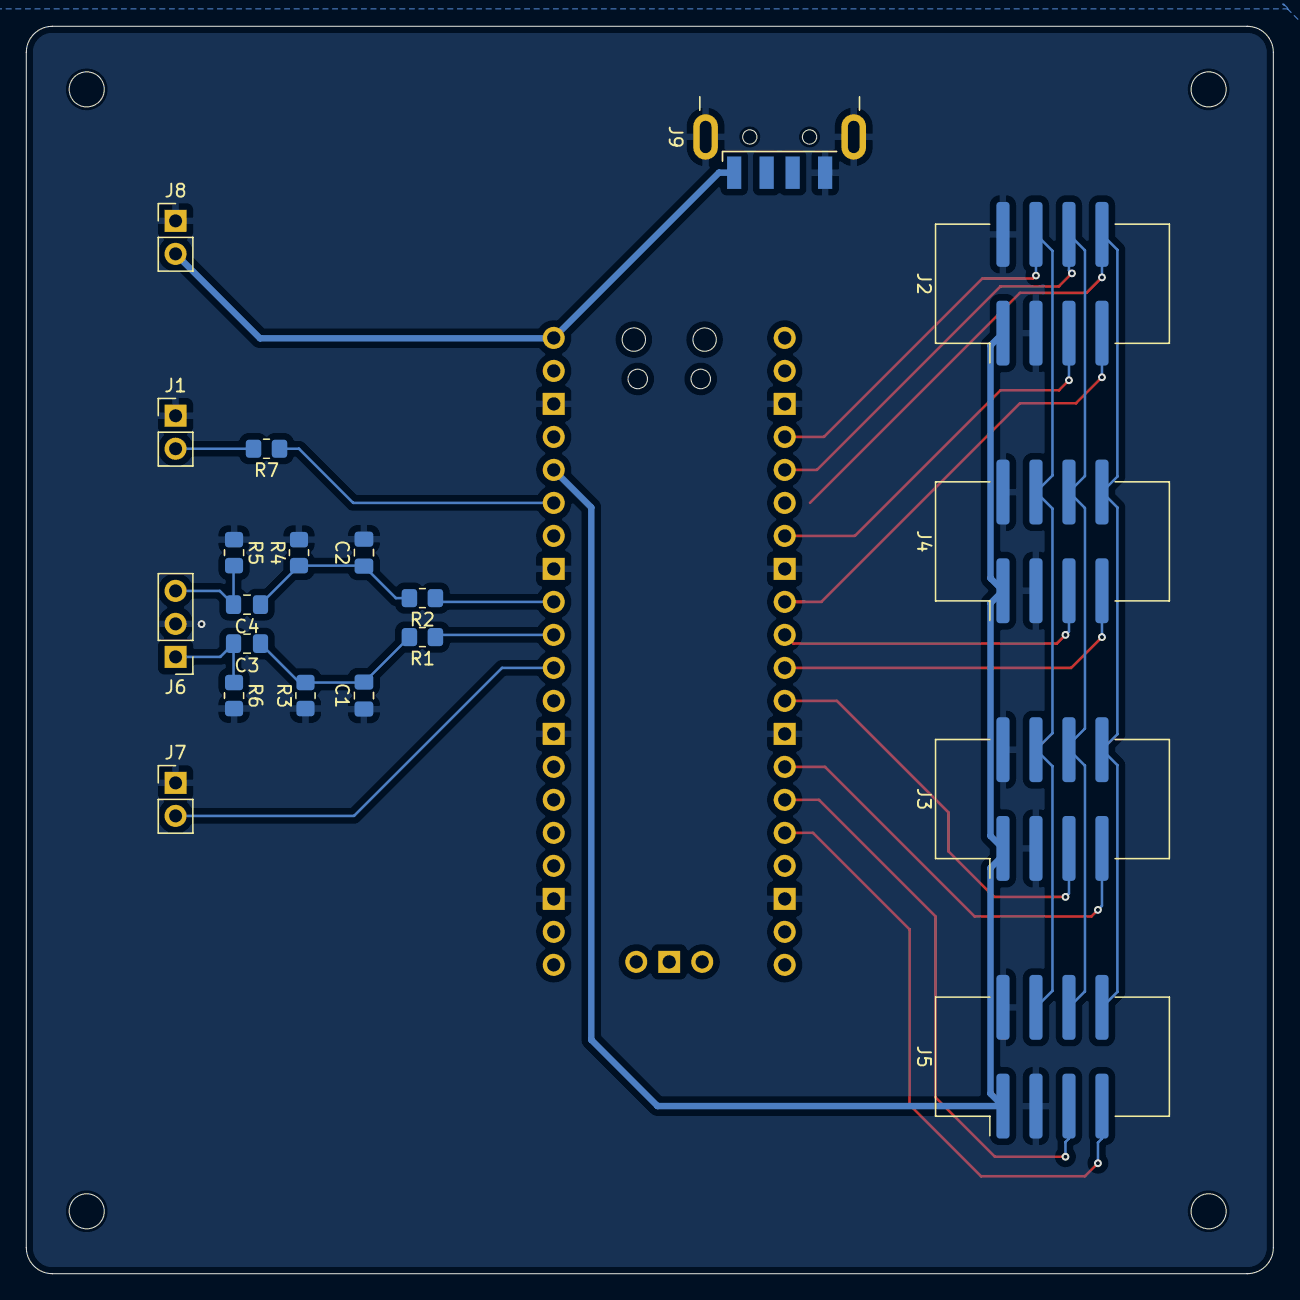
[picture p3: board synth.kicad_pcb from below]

Board: 2 copper layers, 96.0 x 96.0 mm, 25 parts (20 on the bottom side), 25 nets.

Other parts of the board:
H1, H2, H3, H4: MountingHole; MountingHole_2.7mm_M2.5

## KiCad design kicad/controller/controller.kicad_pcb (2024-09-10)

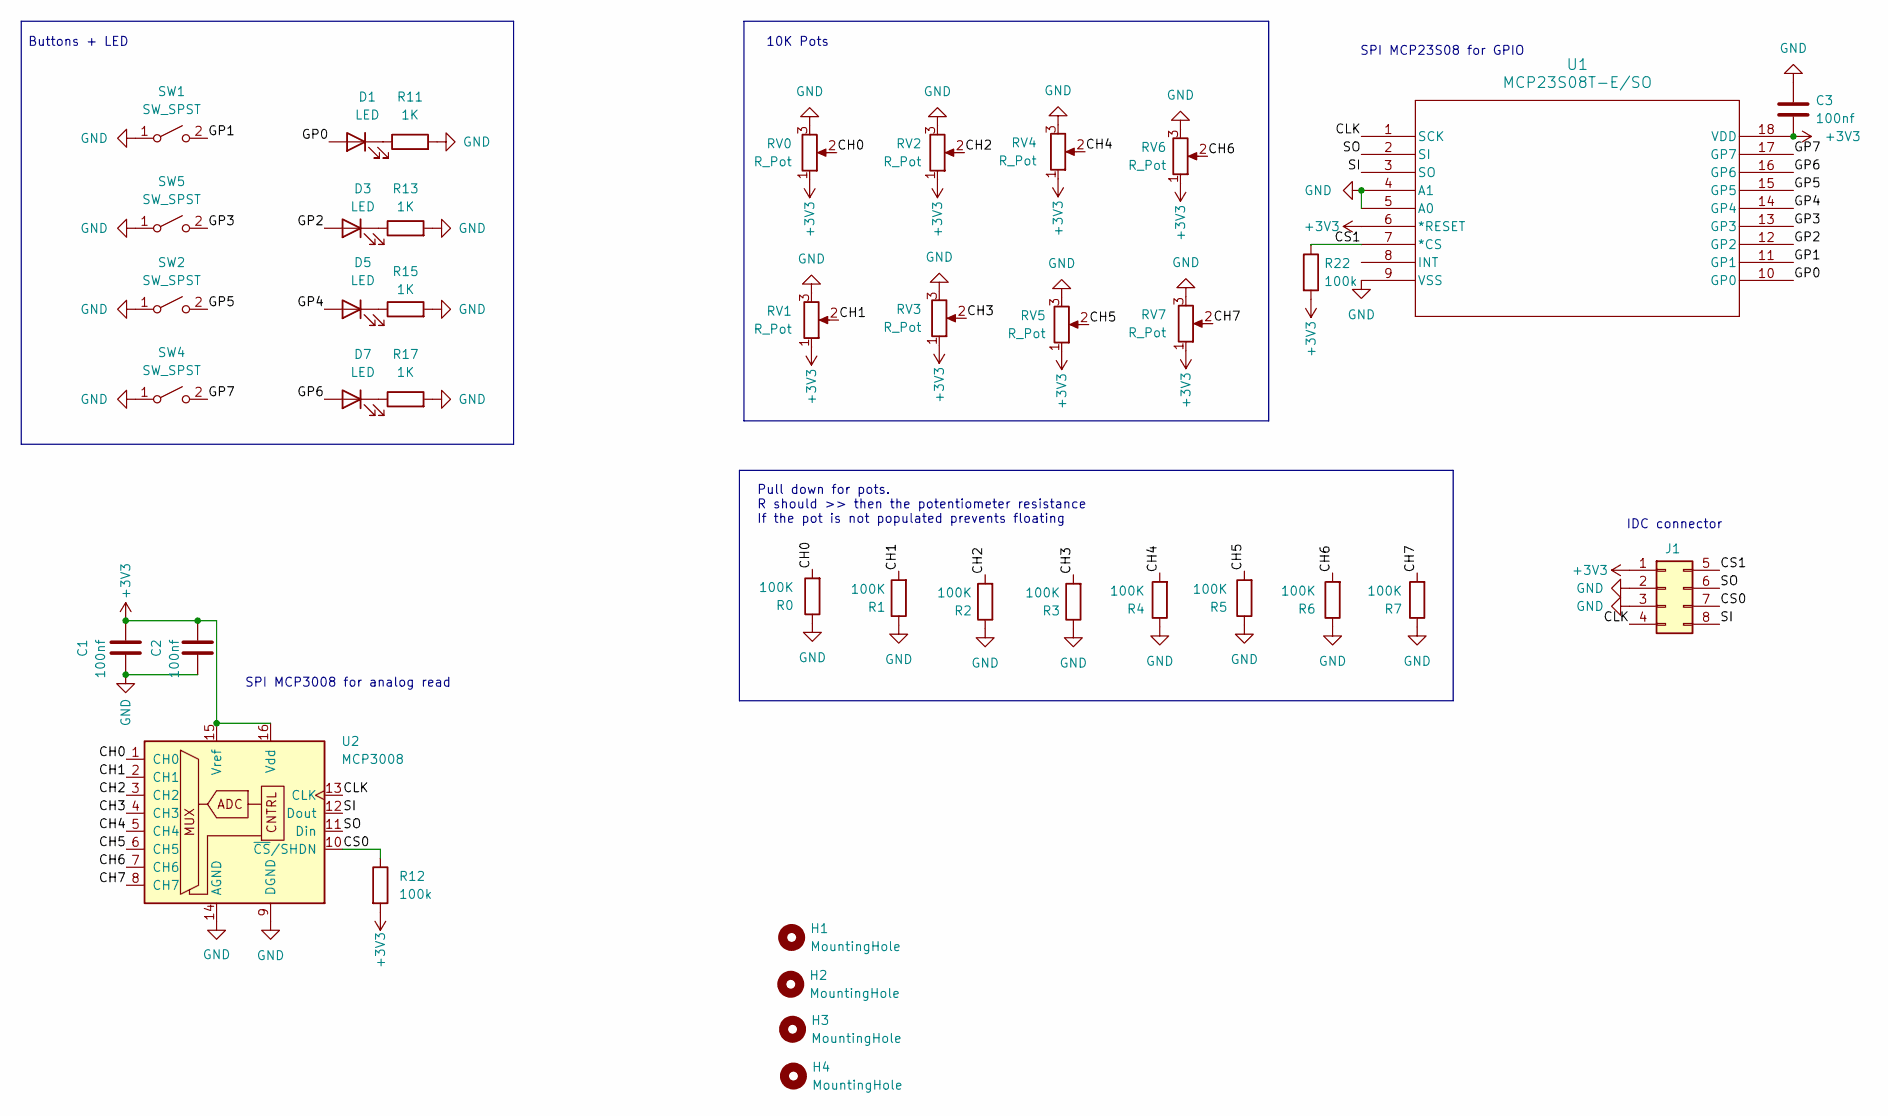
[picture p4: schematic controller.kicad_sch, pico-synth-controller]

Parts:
C1, C2, C3: 100nf; C_0805_2012Metric
D1, D3, D5, D7: LED; LED_D3.0mm_FlatTop
H1, H2, H3, H4: MountingHole; MountingHole_2.7mm_M2.5
J1: Conn_02x04_Top_Bottom; IDC-Header_2x04_P2.54mm_Vertical_SMD
R0, R1, R2, R3, R4, R5, R6, R7: 100K; R_0805_2012Metric
R11, R13, R15, R17: 1K; R_0805_2012Metric
R12, R22: 100k; R_0805_2012Metric
RV0, RV1, RV2, RV3, RV4, RV5, RV6, RV7: R_Pot; Potentiometer_Bourns_PTV09A-1_Single_Vertical
SW1, SW2, SW4, SW5: SW_SPST; SW_PUSH-12mm
U1: MCP23S08T-E/SO; SOIC18-W_MC_MCH
U2: MCP3008; SOIC-16_3.9x9.9mm_P1.27mm

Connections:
+3V3: C1.2, C2.2, C3.2, J1.1, R12.2, R22.2, RV0.1, RV1.1, RV2.1, RV3.1, RV4.1, RV5.1, RV6.1, RV7.1, U1.6 (*RESET), U1.18 (VDD), U2.15 (Vref), U2.16 (Vdd)
/CH0: R0.2, RV0.2, U2.1 (CH0)
/CH1: R1.2, RV1.2, U2.2 (CH1)
/CH2: R2.2, RV2.2, U2.3 (CH2)
/CH3: R3.2, RV3.2, U2.4 (CH3)
/CH4: R4.2, RV4.2, U2.5 (CH4)
/CH5: R5.2, RV5.2, U2.6 (CH5)
/CH6: R6.2, RV6.2, U2.7 (CH6)
/CH7: R7.2, RV7.2, U2.8 (CH7)
/CLK: J1.4, U1.1 (SCK), U2.13 (CLK)
/CS0: J1.7, R12.1, U2.10 (~CS/SHDN)
/CS1: J1.5, R22.1, U1.7 (*CS)
/GP0: D1.2 (A), U1.10 (GP0)
/GP1: SW1.2 (B), U1.11 (GP1)
/GP2: D3.2 (A), U1.12 (GP2)
/GP3: SW5.2 (B), U1.13 (GP3)
/GP4: D5.2 (A), U1.14 (GP4)
/GP5: SW2.2 (B), U1.15 (GP5)
/GP6: D7.2 (A), U1.16 (GP6)
/GP7: SW4.2 (B), U1.17 (GP7)
/SI: J1.8, U1.3 (SO), U2.12 (Dout)
/SO: J1.6, U1.2 (SI), U2.11 (Din)
GND: C1.1, C2.1, C3.1, J1.2, J1.3, R0.1, R1.1, R2.1, R3.1, R4.1, R5.1, R6.1, R7.1, R11.2, R13.2, R15.2, R17.2, RV0.3, RV1.3, RV2.3, RV3.3, RV4.3, RV5.3, RV6.3, RV7.3, SW1.1 (A), SW2.1 (A), SW4.1 (A), SW5.1 (A), U1.4 (A1), U1.5 (A0), U1.9 (VSS), U2.9 (DGND), U2.14 (AGND)
unnamed: D1.1 (K), R11.1
unnamed: D3.1 (K), R13.1
unnamed: D5.1 (K), R15.1
unnamed: D7.1 (K), R17.1

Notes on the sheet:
10K Pots
Buttons + LED
Pull down for pots. R should >> then the potentiometer resistance If the pot is not populated prevents floating
IDC connector
SPI MCP23S08 for GPIO
SPI MCP3008 for analog read

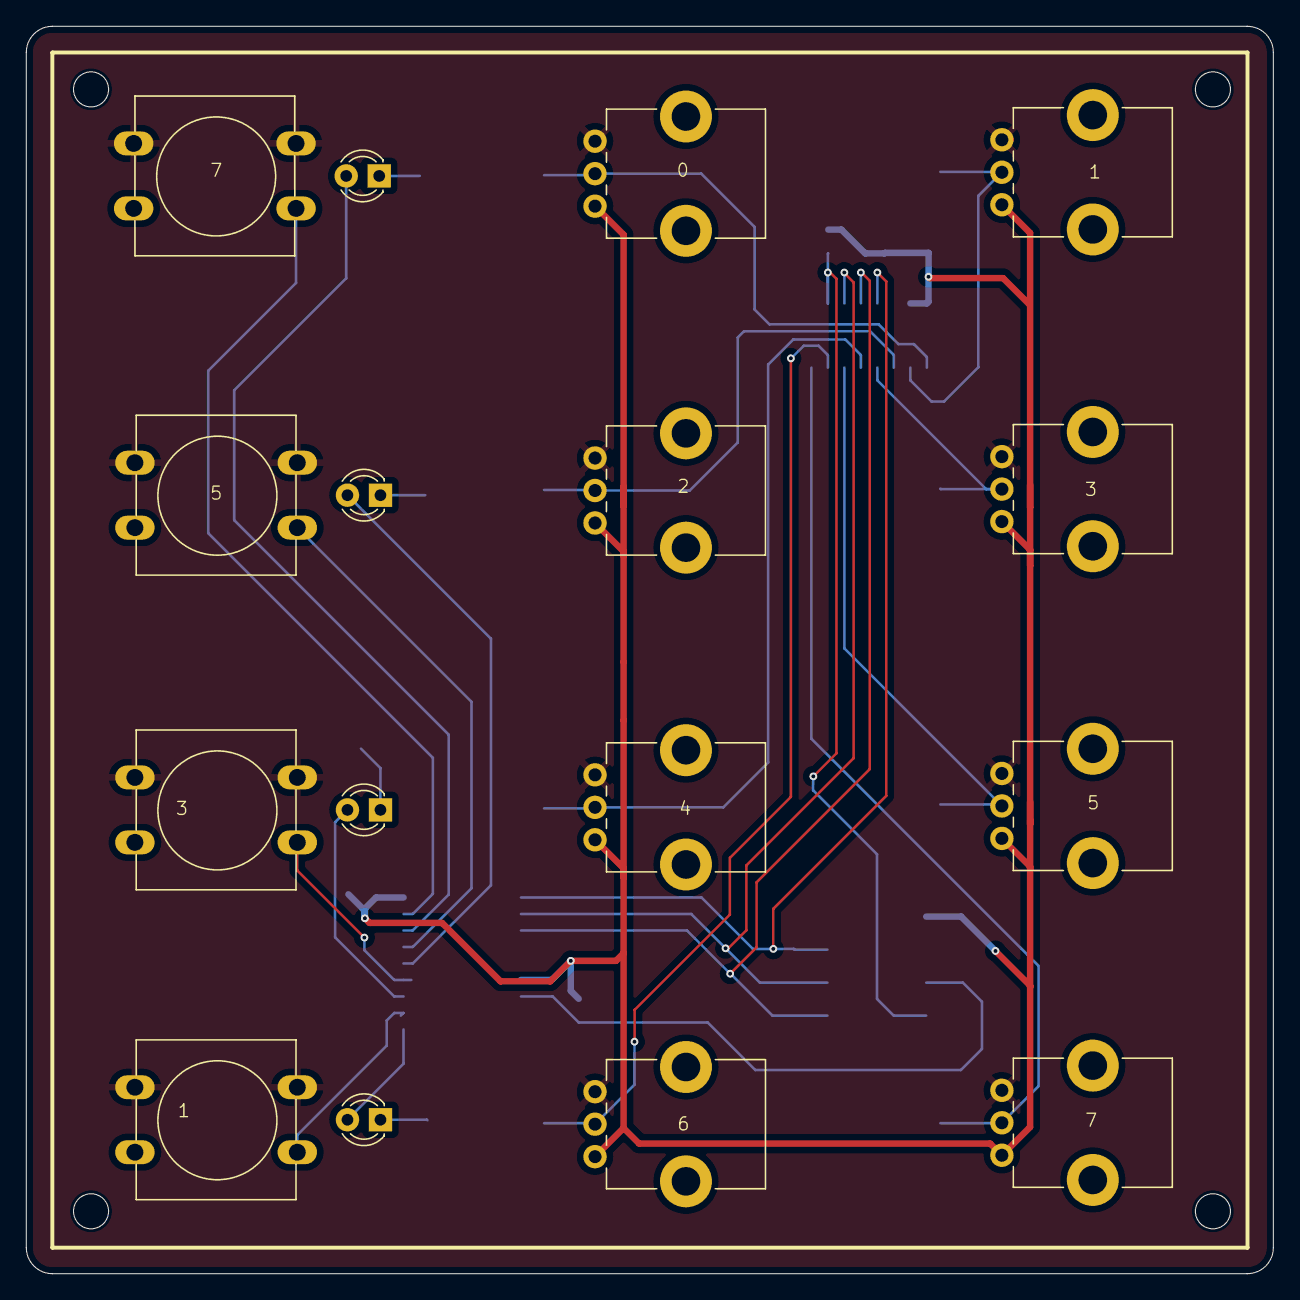
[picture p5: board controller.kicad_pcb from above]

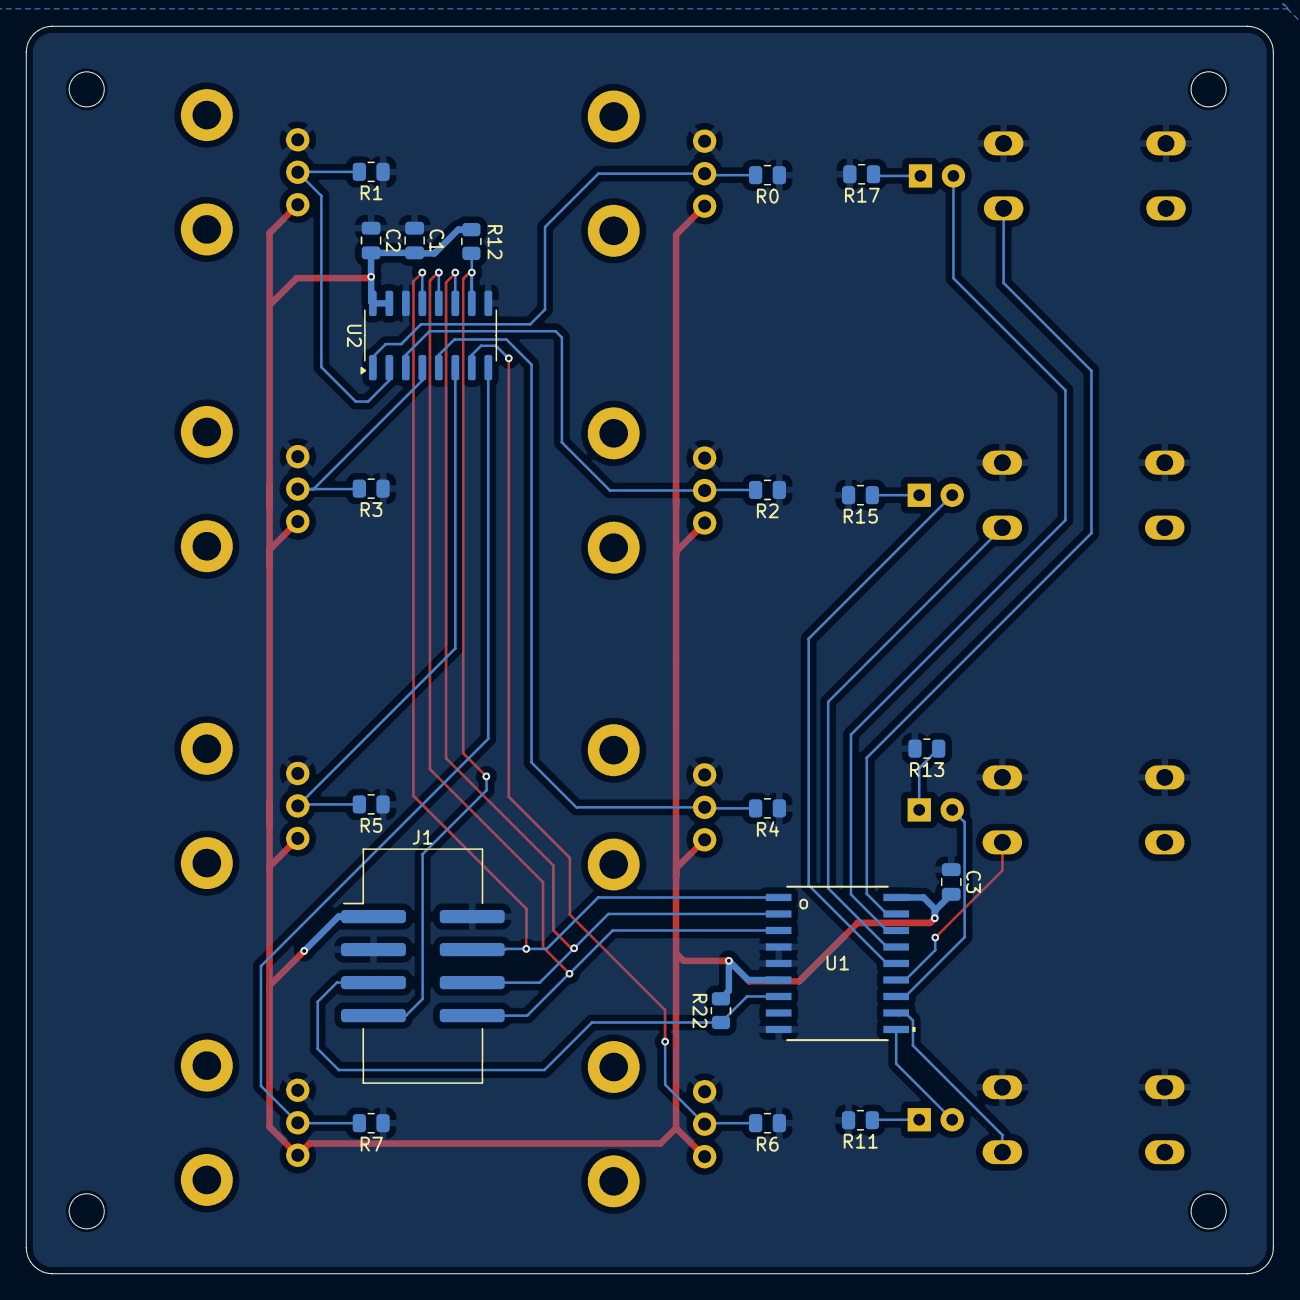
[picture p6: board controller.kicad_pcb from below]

Board: 2 copper layers, 96.0 x 96.0 mm, 40 parts (20 on the bottom side), 27 nets.

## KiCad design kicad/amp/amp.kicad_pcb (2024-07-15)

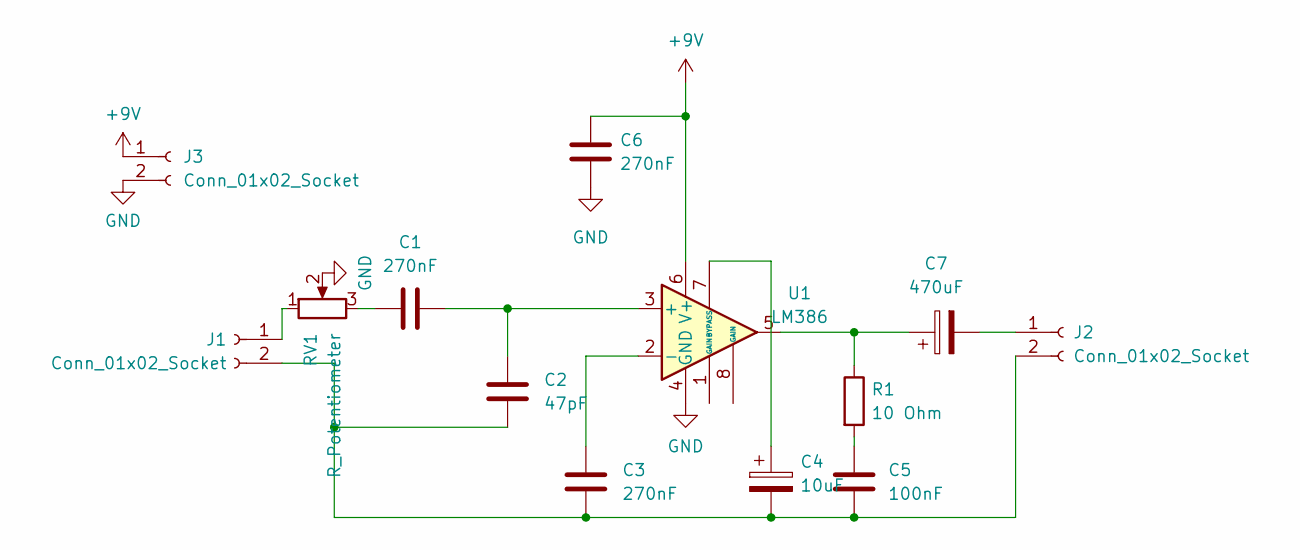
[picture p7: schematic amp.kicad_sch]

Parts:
C1, C3, C6: 270nF; C_Rect_L18.0mm_W5.0mm_P15.00mm_FKS3_FKP3
C2: 47pF; FKP2_04.5WX06.0HX07.2L_WIM
C4: 10uF; CP_Radial_D8.0mm_P3.50mm
C5: 100nF; C_Disc_D5.0mm_W2.5mm_P2.50mm
C7: 470uF; CP_Radial_D8.0mm_P3.50mm
J1, J2, J3: Conn_01x02_Socket; PinHeader_1x02_P2.54mm_Vertical
R1: 10 Ohm; R_Axial_DIN0204_L3.6mm_D1.6mm_P7.62mm_Horizontal
RV1: R_Potentiometer; Potentiometer_Alps_RK09K_Single_Vertical
U1: LM386; N08E_TEX

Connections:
+9V: C6.1, J3.1, U1.6 (V+)
GND: C6.2, J3.2, RV1.2, U1.4 (GND)
unnamed: C1.1, RV1.3
unnamed: C5.1, R1.2
unnamed: C7.1, R1.1, U1.5
unnamed: J1.1, RV1.1
unnamed: C2.2, C3.2, C4.2, C5.2, J1.2, J2.2
unnamed: C7.2, J2.1
unnamed: C1.2, C2.1, U1.3 (+)
unnamed: C3.1, U1.2 (-)
unnamed: C4.1, U1.7 (BYPASS)

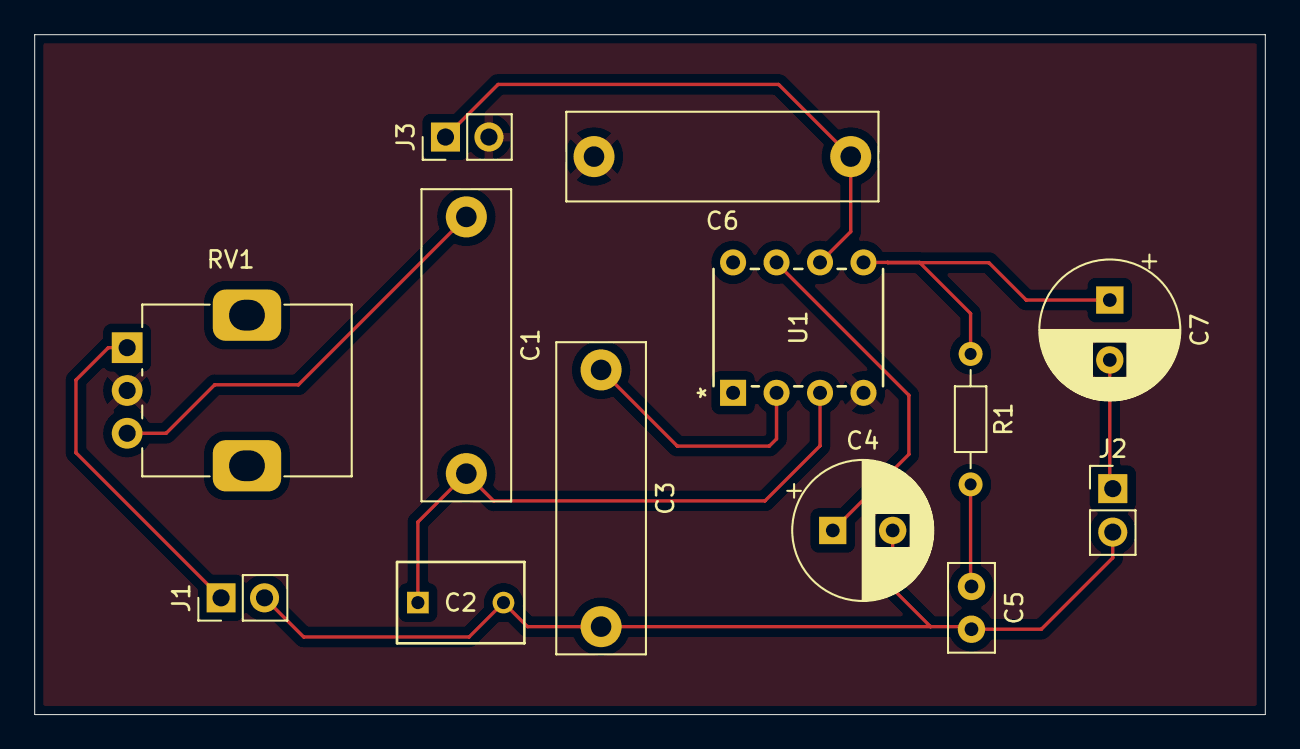
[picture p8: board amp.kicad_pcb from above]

Board: 2 copper layers, 71.9 x 39.7 mm, 13 parts (0 on the bottom side), 11 nets.

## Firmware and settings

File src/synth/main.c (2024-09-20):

#include <math.h>
#include <stdio.h>
#include <stdlib.h>

#include "bsp/board_api.h"
#include "hardware/clocks.h"
#include "hardware/dma.h"
#include "hardware/pwm.h"
#include "hardware/vreg.h"
#include "include/audiocontext.h"
#include "include/controller.h"
#include "include/delay.h"
#include "include/envelope.h"
#include "include/filter.h"
#include "include/fixedpoint.h"
#include "include/metronome.h"
#include "include/midi.h"
#include "include/pitchtable.h"
#include "include/waveform.h"
#include "pico/multicore.h"
#include "pico/stdlib.h"
#include "test.h"
#include "tusb.h"
#include "tusb_config.h"
#include "usb_midi_host.h"
#include "pio_usb.h"

#define PWM_PIN 26

// uncomment to use midi or comment out for the test code
#define USE_MIDI

static uint16_t buffer0[BUFFER_LENGTH] = {0};
static uint16_t buffer1[BUFFER_LENGTH] = {0};
static fix16 raw_buffer[BUFFER_LENGTH] = {0};
static bool swap = false;
static int pwm_dma_channel;
static audio_context_t* context;
static int bit_depth = 12;

static uint8_t midi_dev_addr = 0;

static fix16 previous_dither = 0;
static fix16 dither() {
  // mask off the bottom 8 bits
  uint8_t p = synth_waveform_noise() & 0x00000ff;

  // TODO: not sure about this.  guide is to use 2 LSB of dither
  // not sure if that is 2 LSB on this 32 bit number or on the 12 bit quantized
  // value later? I *think* this setting of _bitDepth + 3 sounds better? but I
  // could be deluding myself I looked at some frequency spectrums with this
  // on/off and various settings the noise floor is raised and skewed to higher
  // frequency might be more noticeable with I2S .  have to wait and see.
  uint8_t depth = bit_depth + 3;
  fix16 dither;

  // these numbers were derived by pissing around in a spreadsheet
  // apply triangular probability
  if (p < 4)
    dither = -57344 >> depth;
  else if (p < 11)
    dither = -49152 >> depth;
  else if (p < 21)
    dither = -40960 >> depth;
  else if (p < 36)
    dither = -32768 >> depth;
  else if (p < 53)
    dither = -24576 >> depth;
  else if (p < 75)
    dither = -16384 >> depth;
  else if (p < 100)
    dither = -8192 >> depth;
  // from here (>=100)
  else if (p < 128)
    dither = 0;
  else if (p < 156)
    dither = 0;
  // to the above accounts for about 22% (56/256)
  else if (p < 181)
    dither = 8192 >> depth;
  else if (p < 203)
    dither = 16384 >> depth;
  else if (p < 220)
    dither = 24576 >> depth;
  else if (p < 235)
    dither = 32768 >> depth;
  else if (p < 245)
    dither = 40960 >> depth;
  else if (p < 252)
    dither = 49152 >> depth;
  else if (p < 256)
    dither = 57344 >> depth;

  // noise shaping
  fix16 result = dither - previous_dither;

  previous_dither = dither;

  return result;
}

static void fill_write_buffer() {
  for (int i = 0; i < BUFFER_LENGTH; i++) {
    fix16 amplitude = 0;

    for (int v = 0; v < VOICES_LENGTH; v++) {
      voice_t* voice = &context->voices[v];

      fix16 sample = synth_waveform_sample(voice, context->pitch_bend);

      amplitude += multfix16(context->velocity, sample);
    }

    // ***** ENVELOPE ******
    context->filter.envelope.envelope =
        synth_envelope_process(&context->filter.envelope);
    fix16 envelope = synth_envelope_process(&context->envelope);
    amplitude = multfix16(amplitude, envelope);
    // *********************

    // apply master gain
    // i have preserved the mix as just summation
    // gain can scale it down to avoid clipping
    amplitude = multfix16(context->gain, amplitude);

    // ***** DITHER ******
    // TODO: not sure I need to introduce noise when I use a breadboard :)
    // if/when I can get control of the sample rate/bit depth again
    // i'll drop it down to 8 or 6 bits (thanks Tony)
    // and hopefully the effect will be more obvious
    // currently I cannot tell the difference
    // amplitude += dither(amplitude);
    // *********************

    // final volume
    context->envelope.envelope = envelope;
    context->raw[i] = amplitude;
    context->samples_elapsed++;
  }

  // ***** FILTER ******
  synth_filter_process(context);
  // *********************

  synth_delay_set_delay(&context->delay);

  // ***** CONVERT TO PWM ******
  // final conversion to PWM
  // amplitude value is fix16 and should be roughly between -1..1
  // need to scale to 0..2^16
  for (size_t i = 0; i < BUFFER_LENGTH; i++) {
    fix16 amplitude = context->raw[i];

    // **** DELAY/ECHO *****
    amplitude += synth_delay_process(&context->delay, amplitude);
    // *********************

    // **** METRONOME *****
    // metronome added after effects
    amplitude += synth_metronome_process(&context->metronome);
    // *********************

    // ***** COMPRESS ******
    // compression, if the amplitude is with -1..1 then compress should not
    // effect too much
    amplitude = tanhfix16(amplitude);
    // *********************

    // the mix value is between -1..1
    // add 1 to move it 0..2
    amplitude = amplitude + FIX16_ONE;

    // scale to an "about 12" bit signal in a 16-bit container
    // we should now have a number between 0..2 (or really 0..1.99999999999
    // need to scale to the bit depth as determined by the wrap calulated on
    // init
    uint16_t out = (uint16_t)(amplitude >> bit_depth);

    context->pwm_out[i] = out;
  }
  // *********************
}

static void __isr __time_critical_func(dma_irq_handler)() {
  // cycle buffers
  context->pwm_out = swap ? buffer0 : buffer1;
  swap = !swap;

  // ack irq
  dma_hw->ints0 = 1u << pwm_dma_channel;
  // restart DMA
  dma_channel_transfer_from_buffer_now(pwm_dma_channel,
                                       swap ? buffer0 : buffer1, BUFFER_LENGTH);

  fill_write_buffer();
}

static uint synth_pwm_init() {
  // derive clk_div and wrap
  // keep clk_div at 1
  uint systemClockHz = frequency_count_khz(CLOCKS_FC0_SRC_VALUE_CLK_SYS) * 1000;

  uint16_t wrap = systemClockHz / SAMPLE_RATE;
  bit_depth = 16 - floorf(log2f(wrap + 1));

  // setup pwm
  gpio_set_function(PWM_PIN, GPIO_FUNC_PWM);
  gpio_set_function(PWM_PIN + 1, GPIO_FUNC_PWM);
  uint slice = pwm_gpio_to_slice_num(PWM_PIN);
  pwm_config pwmConfig = pwm_get_default_config();

  // set sample rate/clock to 125Mhz / wrap+1 / div =   ~22kHz
  // rp2040 datasheet gives the actual formula

  pwm_config_set_clkdiv(&pwmConfig, 1.f);
  pwm_config_set_wrap(&pwmConfig, wrap);
  // pwm_config_set_phase_correct(&pwmConfig, true);
  pwm_init(slice, &pwmConfig, true);

  return slice;
}

static void synth_dma_init(uint slice) {
  // setup dma
  pwm_dma_channel = dma_claim_unused_channel(true);

  dma_channel_config dmaConfig =
      dma_channel_get_default_config(pwm_dma_channel);
  // must be 16 bits
  channel_config_set_transfer_data_size(&dmaConfig, DMA_SIZE_16);
  channel_config_set_read_increment(&dmaConfig, true);
  channel_config_set_write_increment(&dmaConfig, false);
  channel_config_set_dreq(&dmaConfig, DREQ_PWM_WRAP0 + slice);

  dma_channel_configure(
      pwm_dma_channel, &dmaConfig,
      &pwm_hw->slice[slice].cc,  // Write to PWM counter compare
      &buffer0,                  // read from buffer
      BUFFER_LENGTH,             // number of transfers to perform
      true                       // start
  );

  dma_channel_set_irq0_enabled(pwm_dma_channel, true);
  irq_set_exclusive_handler(DMA_IRQ_0, dma_irq_handler);
  irq_set_enabled(DMA_IRQ_0, true);
}

static void synth_audio_context_init() {
  context = malloc(sizeof(audio_context_t));

  context->delay.enabled = false;
  context->metronome.enabled = false;
  context->filter.enabled = false;

  context->raw = raw_buffer;
  context->pwm_out = buffer1;
  context->sample_rate = SAMPLE_RATE;
  context->samples_elapsed = 0;
  context->gain = FIX16_POINT_7;
  context->mod_wheel = 0;
  context->pitch_bend = FIX16_ONE;
  context->velocity = FIX16_POINT_5;

  context->delay.delay_in_samples = 0;
  context->filter.follow_voice_envelope = true;
  context->filter.resonance = 0;
  context->filter.cutoff = 0;
  context->filter.envelope.state = OFF;
  context->filter.envelope.envelope = 0;
  context->filter.envelope.elapsed = 0;
  context->filter.envelope.duration = 0;
  context->filter.envelope.attack =
      synth_envelope_to_duration(float2fix16(0.01f));
  context->filter.envelope.decay =
      synth_envelope_to_duration(float2fix16(0.03f));
  context->filter.envelope.sustain = FIX16_POINT_7;
  context->filter.envelope.release =
      synth_envelope_to_duration(float2fix16(0.4f));
  context->filter.envelope_depth = FIX16_ONE;

  context->envelope.state = OFF;
  context->envelope.envelope = 0;
  context->envelope.elapsed = 0;
  context->envelope.duration = 0;
  context->envelope.trigger_attack = false;
  context->envelope.attack = synth_envelope_to_duration(float2fix16(0.01f));
  context->envelope.decay = synth_envelope_to_duration(float2fix16(0.03f));
  context->envelope.sustain = FIX16_POINT_7;
  context->envelope.release = synth_envelope_to_duration(float2fix16(0.03f));

  for (int v = 0; v < VOICES_LENGTH; v++) {
    context->voices[v].frequency = PITCH_C3;
    context->voices[v].waveform = SAW;
    context->voices[v].detune = 0;
    context->voices[v].wavetable_phase = 0;
    context->voices[v].width = FIX16_POINT_5;
    synth_waveform_set_wavetable_stride(&context->voices[v], 0);
  }
}

void init_all() {
  board_init();
  synth_waveform_init();
  synth_audio_context_init();
  synth_metronome_init(&context->metronome, 120);
  synth_filter_init(context);
  synth_delay_init();
  uint slice = synth_pwm_init();
  

#ifdef USE_MIDI
  // midi is intialised when mounted
  pio_usb_configuration_t pio_cfg = PIO_USB_DEFAULT_CONFIG;
  
  tuh_configure(BOARD_TUH_RHPORT, TUH_CFGID_RPI_PIO_USB_CONFIGURATION, &pio_cfg);
  tuh_init(BOARD_TUH_RHPORT);
  tud_init(BOARD_TUD_RHPORT);

  synth_dma_init(slice);
  synth_controller_init();

  // read to initialise to the state of the physical controls
  synth_controller_task(context);
#endif
}

void core1_worker() {
  while (true) {
#ifndef USE_MIDI
    // TODO: the player has a load of sleeps
    // it's not really a sequencer
    synth_test_play(context);
#else
    tuh_task();
    tud_task();
    synth_midi_device_task(context);
#endif
  }
}

int main() {
  // https://www.raspberrypi.com/documentation/pico-sdk/runtime.html#pico_bootsel_via_double_reset
  // pico_bootsel_via_double_reset is linked in CMakeLists.txt

  // can go to 420MHz set vreg to 1.3
  vreg_set_voltage(VREG_VOLTAGE_1_15);
  // must be multiple of 12MHz for USB PIO
  set_sys_clock_khz(320000, true);

  stdio_init_all();
  init_all();

  uint systemClockHz = frequency_count_khz(CLOCKS_FC0_SRC_VALUE_CLK_SYS) / 1000;

  printf("\n----------------------\nSynth starting.\n");
  printf("system clock: %uMHz\n", systemClockHz);
  printf("sample rate: %dHz\n", SAMPLE_RATE);
  printf("bit depth: %d\n", 16 - bit_depth);
  synth_audiocontext_debug(context);
  printf("\n----------------------\n");

  // run USB tasks
  multicore_launch_core1(core1_worker);

  // run input tasks
  while (1) {
    // SPI clock for the controller is set to 3.6Mhz
    // which runs at about 35 uSecond
    // so in theory this could be run on a timer at half sample rate or 16kHz
    // TODO: see how stable it at this clock - previously was running at 120Khz
    // so 3.6MHz is a bit of a jump
    // also - has to query 64 controls if I expose all features
    // so I need some headroom

    // uint32_t start = time_us_32();
    synth_controller_task(context);
    // uint32_t end = time_us_32();
    // printf("%uus\n", end-start);
  }
}

//--------------------------------------------------------------------+
// TinyUSB Callbacks
//--------------------------------------------------------------------+

// Invoked when device with hid interface is mounted
// Report descriptor is also available for use.
// tuh_hid_parse_report_descriptor() can be used to parse common/simple enough
// descriptor. Note: if report descriptor length > CFG_TUH_ENUMERATION_BUFSIZE,
// it will be skipped therefore report_desc = NULL, desc_len = 0
void tuh_midi_mount_cb(uint8_t dev_addr, uint8_t in_ep, uint8_t out_ep,
                       uint8_t num_cables_rx, uint16_t num_cables_tx) {
  printf(
      "MIDI device address = %u, IN endpoint %u has %u cables, OUT endpoint %u "
      "has %u cables\r\n",
      dev_addr, in_ep & 0xf, num_cables_rx, out_ep & 0xf, num_cables_tx);

  if (midi_dev_addr == 0) {
    // then no MIDI device is currently connected
    midi_dev_addr = dev_addr;

    // init midi here as we get can get some random messages in the queue if you
    // were hitting keys on a midi controller while the pico boots
    synth_midi_init(context);
  } else {
    printf(
        "A different USB MIDI Device is already connected.\r\nOnly one device "
        "at a time is supported in this program\r\nDevice is disabled\r\n");
  }
}

// Invoked when device with hid interface is un-mounted
void tuh_midi_umount_cb(uint8_t dev_addr, uint8_t instance) {
  if (dev_addr == midi_dev_addr) {
    midi_dev_addr = 0;
    printf("MIDI device address = %d, instance = %d is unmounted\r\n", dev_addr,
           instance);
  } else {
    printf("Unused MIDI device address = %d, instance = %d is unmounted\r\n",
           dev_addr, instance);
  }
}

void tuh_midi_rx_cb(uint8_t dev_addr, uint32_t num_packets) {
  if (midi_dev_addr == dev_addr) {
    if (num_packets != 0) {
      uint8_t cable_num;
      uint8_t buffer[48];
      while (1) {
        uint32_t bytes_read =
            tuh_midi_stream_read(dev_addr, &cable_num, buffer, sizeof(buffer));
        if (bytes_read == 0) return;
        synth_midi_host_task(context, buffer);
      }
    }
  }
}

void tuh_midi_tx_cb(uint8_t dev_addr) { (void)dev_addr; }

void tuh_hid_report_received_cb(uint8_t dev_addr, uint8_t instance,
                                uint8_t const *report, uint16_t len) {
}

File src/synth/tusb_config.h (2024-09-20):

/* 
 * The MIT License (MIT)
 *
 * Copyright (c) 2019 Ha Thach (tinyusb.org)
 *
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
 */

#ifndef _TUSB_CONFIG_H_
#define _TUSB_CONFIG_H_

#ifdef __cplusplus
 extern "C" {
#endif

// enabling DEBUG glitches the audio, so watch out for that
// #undef CFG_TUSB_DEBUG
// #define CFG_TUSB_DEBUG  3


// RHPort number used for device can be defined by board.mk, default to port 0
#ifndef BOARD_TUD_RHPORT
#define BOARD_TUD_RHPORT      0
#endif

// RHPort max operational speed can defined by board.mk
#ifndef BOARD_TUD_MAX_SPEED
#define BOARD_TUD_MAX_SPEED   OPT_MODE_DEFAULT_SPEED
#endif

// RHPort number used for host can be defined by board.mk, default to port 1
#ifndef BOARD_TUH_RHPORT
#define BOARD_TUH_RHPORT      1
#endif

// RHPort max operational speed can defined by board.mk
#ifndef BOARD_TUH_MAX_SPEED
#define BOARD_TUH_MAX_SPEED   OPT_MODE_DEFAULT_SPEED
#endif

//--------------------------------------------------------------------
// COMMON CONFIGURATION
//--------------------------------------------------------------------

// defined by compiler flags for flexibility
#ifndef CFG_TUSB_MCU
#error CFG_TUSB_MCU must be defined
#endif

#ifndef CFG_TUSB_OS
#define CFG_TUSB_OS           OPT_OS_NONE
#endif

#ifndef CFG_TUSB_DEBUG
#define CFG_TUSB_DEBUG        0
#endif

// Enable Device stack, Default is max speed that hardware controller could support with on-chip PHY
#define CFG_TUD_ENABLED       1
#define CFG_TUD_MAX_SPEED     BOARD_TUD_MAX_SPEED

// Enable Host stack, Default is max speed that hardware controller could support with on-chip PHY
#define CFG_TUH_ENABLED       1
#define CFG_TUH_MAX_SPEED     BOARD_TUH_MAX_SPEED

#if CFG_TUSB_MCU == OPT_MCU_RP2040
// Use pico-pio-usb as host controller for raspberry rp2040
// TODO: this at least compiles somehow - using TUD does not
// disable for now as the GPIO and DMA conflict
#define CFG_TUH_RPI_PIO_USB   1
#endif



/* USB DMA on some MCUs can only access a specific SRAM region with restriction on alignment.
 * Tinyusb use follows macros to declare transferring memory so that they can be put
 * into those specific section.
 * e.g
 * - CFG_TUSB_MEM SECTION : __attribute__ (( section(".usb_ram") ))
 * - CFG_TUSB_MEM_ALIGN   : __attribute__ ((aligned(4)))
 */
#ifndef CFG_TUSB_MEM_SECTION
#define CFG_TUSB_MEM_SECTION
#endif

#ifndef CFG_TUSB_MEM_ALIGN
#define CFG_TUSB_MEM_ALIGN          __attribute__ ((aligned(4)))
#endif

//--------------------------------------------------------------------
// CONFIGURATION
//--------------------------------------------------------------------

// Size of buffer to hold descriptors and other data used for enumeration
#define CFG_TUH_ENUMERATION_BUFSIZE 400

#define CFG_TUH_HUB                 1 // Enable USB hubs
#define CFG_TUH_CDC                 0
#define CFG_TUH_HID                 (3 * CFG_TUH_DEVICE_MAX) // typical keyboard + mouse device can have 3-4 HID interfaces
//NOTE: Do note #define CFG_TUH_MIDI 1 to enable MIDI Host. A code fragment in usbh.c that breaks the build if you do that
#define CFG_TUH_MSC                 0
#define CFG_TUH_VENDOR              0

// max device support (excluding hub device)
#define CFG_TUH_DEVICE_MAX          (CFG_TUH_HUB ? 4 : 1) // hub typically has 4 ports

// MIDI Host string support
#define CFG_MIDI_HOST_DEVSTRINGS 1

#ifndef CFG_TUH_MEM_SECTION
#define CFG_TUH_MEM_SECTION
#endif

#ifndef CFG_TUH_MEM_ALIGN
#define CFG_TUH_MEM_ALIGN           __attribute__ ((aligned(4)))
#endif
//--------------------------------------------------------------------
// DEVICE CONFIGURATION
//--------------------------------------------------------------------

#ifndef CFG_TUD_ENDPOINT0_SIZE
#define CFG_TUD_ENDPOINT0_SIZE    64
#endif

//------------- CLASS -------------//
#define CFG_TUD_CDC               0
#define CFG_TUD_MSC               0
#define CFG_TUD_HID               0
#define CFG_TUD_MIDI              1
#define CFG_TUD_VENDOR            0

// MIDI FIFO size of TX and RX
#define CFG_TUD_MIDI_RX_BUFSIZE   (TUD_OPT_HIGH_SPEED ? 512 : 64)
#define CFG_TUD_MIDI_TX_BUFSIZE   (TUD_OPT_HIGH_SPEED ? 512 : 64)


#ifdef __cplusplus
 }
#endif

#endif /* _TUSB_CONFIG_H_ */

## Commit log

2023-07-09 Update pico synth.md
2023-07-11 use DMA to send data to PWM
2023-07-14 noise works :) triangle sounds whack
    [main.c]
2023-07-16 simplify my use of a pointer to current buffer. Debugging why trianlge goes click? no idea...
2023-07-18 fixed silly triangle wave issues
    [main.c]
2023-07-22 envelope generation, loosely based on my old c# code. I tried using funciton pointers to mimic the FP approach and it as quite confusing... ending up with a state machine
    [main.c]
2023-07-23 get UART and SWD working
2023-07-25 monophonic using three voices/oscillators. dodgy note priority and detune
    [main.c]
2023-07-26 add low pass filter and some MIDI cc to control it
2023-07-27 just mucking around, wired in a few more midi CC knobs
2023-08-03 bit of an overhaul to use fixed point. not quite finished and there are few odd artifacts, but performance is looking good
    [main.c]
2023-08-03 more fixed point. I have given up on the filter for now as it sounds bad. I can now achieve a high rate of over 300kHz and the sound is pretty decent.
    [main.c]
2023-08-06 fix bug in envelope, needed an epsilon(?) value as we would not always be exactly == 0. change pwm clock to target a sample rate, this increases the bit depth to 13 bits which sounds nicer
    [main.c]
2023-08-08 add some delay and wire in some midi to control it
2023-08-10 tweaking things and see what performance I can get - hitting 20 oscillators at 32767Hz. thinking about how I could use the second core
    [main.c]
2023-08-12 fixing the bugs i just added
    [main.c]
2023-08-13 the no_flash option is RAM only and led to much confusion for me. Let's actually update the firmware instead...
2023-08-14 another bug maybe i need more types
    [main.c]
2024-06-25 wire in a few pots
2024-07-01 saw wave was wrong!
    [main.c]
2024-07-01 get the filter working somewhat
2024-07-01 rework the main pipeline that generates sound and check filter+delay+metronome is ok
    [main.c]
2024-07-02 fix some bugs and add pitch bend. broke square wave
    [main.c]
2024-07-02 fix squarewave and add pulse width
    [main.c]
2024-07-06 ignore kicad back files
2024-07-08 begin refactoring voice to a set of oscillators. add dry/wet mix to delay. sketching out a generic UI pcb
    [controller.kicad_pcb, controller.kicad_sch]
2024-07-09 fix some bugs in the delay wet/dy and in the pitch bend
    [main.c]
2024-07-10 fix bug with the detune as it is addition and no longer a multiplication
    [main.c]
2024-07-11 tweak metronome and make a LED blink
    [controller.kicad_pcb, controller.kicad_sch]
2024-07-11 trying to add USB host and device simultaneously
    [synth.kicad_pcb, synth.kicad_sch]
2024-07-15 sketch out LM386 amp
    [amp.kicad_pcb, amp.kicad_sch, synth.kicad_pcb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]
2024-08-13 start adding mcp23s08 gpio extender
    [controller.kicad_sch]
2024-08-17 fix side-set logic - bool is NOT a char!
    [controller.kicad_sch]
2024-09-06 fix button behaviour now I have a PCB
    [controller-B_Cu.gbr, controller-B_Mask.gbr, controller-B_Paste.gbr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]
2024-09-10 fiddling with the config as I test the PCB
    [controller.kicad_pcb]
2024-09-10 removed debounce as in practice it did not help
    [controller.kicad_pcb, controller.kicad_sch]
2024-09-11 move uart pins and prepare for PIO USB
    [synth.kicad_sch]
2024-09-20 USB PIO now works and can control via PC or direct MIDI device :)
    [amp.kicad_sch, synth.kicad_pcb, synth.kicad_sch]
